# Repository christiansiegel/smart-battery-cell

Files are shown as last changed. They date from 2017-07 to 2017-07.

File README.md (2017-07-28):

# Arduino-based Smart Battery Cell Research Platform

Accessible smart battery cell research platform based on the Arduino environment. Smart battery cells are a recent research direction in the scope of Battery Management Systems (BMS) for large lithium-ion battery packs, where each battery cell is equipped with an individual Cell Management Unit (CMU). The wireless System on Chip (SOC) solution ESP8266 forms the core of the research platform. It is deployed on an off-the-shelf development board and extended with a custom shield. A single-board computer provides the wireless network for the smart battery cells and acts as gateway to a web service for interaction purposes. As a proof-of-concept, a web client is created that communicates with the battery pack via the MQTT protocol.

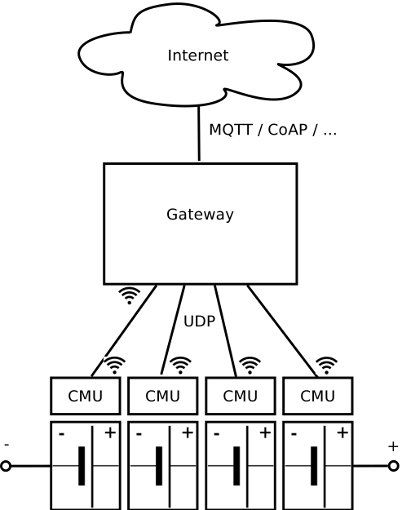
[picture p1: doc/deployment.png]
Deployment Diagram


## Repository Structure

### cloud
Cloud server running MQTT broker and Webserver. See [setup guide](cloud/README.md) for more details.

### cmu
Cell Management Unit Arduino sketch.

### doc
Documentation comprising a [PDF paper](doc/paper.pdf) and a more detailed [PDF report](doc/report.pdf).

### gateway
Gateway Java code. Also contains a [setup guide](gateway/README.md) for a Raspberry Pi 3.

### schematic
Schematic design files (CadSoft EAGLE) of the smart battery cell.

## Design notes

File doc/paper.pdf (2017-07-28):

# Arduino-based Smart Battery Cell Research Platform

Christian Siegel, Aarhus University

(Engineering Research and Development Project)

Abstract—This paper introduces an accessible smart battery cell research platform based on the Arduino environment. Smart battery cells are a recent research direction in the scope of Battery Management Systems (BMS) for large lithium-ion battery packs, where each battery cell is equipped with an individual Cell Management Unit (CMU). The wireless System on Chip (SOC) solution ESP8266 forms the core of the research platform. It is deployed on an off-the-shelf development board and extended with a custom shield. A single-board computer provides the wireless network for the smart battery cells and acts as gateway to a web service for interaction purposes. As a proof-of-concept, a web client is created that communicates with the battery pack via the MQTT protocol.

I. INTRODUCTION
L
ITHIUM Ion (Li-Ion) batteries are utilized in most emerging electrically powered technologies such as electric vehicles, power tools or stationary energy storages. Large battery packs are made of battery cells connected in series and parallel to achieve a desired voltage and capacity. Due to their chemical properties, Li-Ion cells must be operated in strictly specified voltage, current, and temperature ranges to avoid critical damages to the battery cells. State-of-theart battery packs use a central Battery Management Systems (BMS) to monitor cell parameters and control the charge and discharge of cells in a battery pack. Since these BMS are tied to a specific battery pack architecture they need to be customly developed. A recent proposal is to move the battery pack management from a centralized BMS towards individual Cell Management Units (CMU) at the cell level [1]. This leads to more flexibility in composing the battery pack architecture and reduces development time. Furthermore, the reduced battery pack complexity simplifies efficient charge transfer between individual cells, compared to traditional passive balancing, in order to equalize the State of Charge (SoC) of all battery cells. Contributions of this paper. Recent research on smart battery cells was conducted on pricey custom development platforms incorporating powerful microcontrollers and realtime operating systems. Contribution of this paper is to introduce a more accessible smart battery cell research platform based on the Arduino platform, using mainly off-the-shelf hardware components. In section II, related work and its proposed solutions are investigated. Section III discusses and describes the used hardware and modifications made. The software is depicted in section IV. Finally, a conclusion is drawn in section V.

II. RELATED WORK
Previous research was conducted on rather powerful and pricey hardware like a STM32F407 Cortex-M4 microcon-

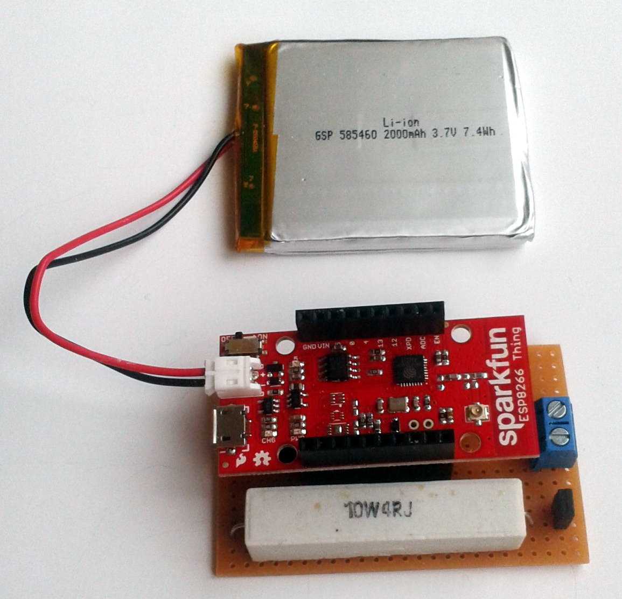
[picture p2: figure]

Fig. 1. Smart battery cell comprised of an ESP8266 development board, an extension shield, and a battery cell.

troller board [1][2]. The microcontroller was connected to the battery cell through a custom designed sensor and control board, which could be interfaced using a Serial Periphal Interface (SPI) bus. The invidual smart cells communicated via a Controller Area Network (CAN) bus connected to the microcontroller boards [1].
Especially communication poses a significant challenge, since wired busses like CAN, Ethernet, Inter-Integrated Circuit (I²C), or Universal Asynchronous Receiver/Transmitter (UART) require a common ground potential. If the smart cells are connected in series, there is no common ground and the bus has to be galvanically separated using e.g. optocouplers.
[3] and [4] propose and demonstrate the use of contactless communication via capacitive coupling for distributed monitoring and controlling of battery cells. This technology can also be applied for communication between smart battery cells. Main disadvantage of this approach is the need for additional communication hardware which is not available off-the-shelf.
[5] proposes wireless communication for monitoring lead acid vehicle batteries. The emerging trend of an Internet of Things (IoT) leads to a range of hardware manufacturers offering low-cost wireless System on Chip (SOC) solutions. A full TCP/IP stack provides a well known, and convenient to use protocol suite for distributed systems.

III. HARDWARE

This section discusses the hardware choices made in order to realise the Arduino-based smart battery cell research platform, which is shown in Fig. 1.

TABLE I
COMPARISON OF WIRELESS SOC MCU PROPERTIES [6][7]
ESP8266 | CC3200
Core | Tensilica L106 | ARM Cortex-M4
Clock | 80 – 160 MHz | 80 MHz
RAM | ∼50 kB usable in station mode | ≤256 kB
Flash | external | external
I/Os | 16 | 27
ADC | 1x 10-bit | 4x 12-bit
2C I | 1 | 1
SPI | 1 | 1
UART | 1 | 2

TABLE II
COMPARISON OF WIRELESS SOC POWER CONSUMPTIONS [6][7]
ESP8266 | CC3200
Tx | ∼145 mA | ∼215 mA
Rx | 56 mA | 59 mA
Modem idle/sleep | 15 mA | 15.3 mA
Deep-Sleep | 10 µA | 4 µA
A. Development Board

To prevent the need for a pricey, customly designed circuit board, the research platform should be based on an offthe-shelf Microcontroller Unit (MCU) development board. In order to further reduce the need of additional hardware, this development board should also comprise a communication interface. As already mentioned in section II, there are wireless SOCs available that meet these requirements, like the Espressif Systems ESP8266¹ or the Texas Instruments CC3200²
. The
MCU properties of the named SOCs are outlined in Table
I. Both MCUs have a 32-bit core. While the CC3200’s core can be clocked at maximum 80 MHz, the ESP8266’s core clock can be increased up to 160 MHz. With around 50 kB of usable RAM in station mode, the ESP8266 has significantly less RAM than the CC3200, which provides 256 kB. Both the ESP8266 and the CC3200 don’t come with internal flash storage. The CC3200 has almost twice the amount of general purpose I/Os than the ESP8266, and four ADCs instead of one. The CC3200’s ADCs also have a higher resolution of 12 bits, compared to the 10-bit ADC of the ESP8266.
Since the CMU is powered by a battery cell, its power consumption is an important figure to maximize the smart battery cell’s capacity. Table II shows the power consumption of both wireless SOCs. The ESP8266 typically draws less current while sending than the CC3200, with ∼145 mA and ∼215 mA respectively. However, the transmission current heavily depends on the WLAN protocol and the transmission power, which can be configured. The receiving current difference is mimimal, with typically 56 mA for the ESP8266 and 59 mA for the CC3200. When the wireless module in sleeping mode, both wireless SOCs also draw almost the same current, with 15 mA and 15.3 mA respectively. In the deepest sleeping mode both devices use ≤10 µA.
Although the ESP8266 is inferior to the CC3200 regarding hardware features, it is chosen as the core of the research

1https://espressif.com/en/products/hardware/esp8266ex/overview2http://www.ti.com/product/CC3200

platform. This is due to a significant lower price while still meeting the requirements for the platform. The SOC is deployed on the SparkFun ESP8266 Thing³ development board. It comprises an ESP8266, flash storage, an antenna, an onboard Li-Po charging circuit, and a JST socket to connect a battery cell. Hence, only the passive cell balancing, and the voltage measurement circuits need to be added externally.

B. Battery
A prismatic, 2000 mAh Li-Po battery with a JST connector is used. It can be directly plugged into the development board. Its capacity is similar to industrial 18650 cylindrical cells, which typically provide around 2500 mAh. This enables it to power the CMU for several hours without recharging. Furthermore, the battery has a built-in protection circuit to prevent damage to the cell if used improperly.
C. Extension Shield
The remaining additional hardware components are combined to an extension shield for the development board.
The SparkFun ESP8266 Thing board doesn’t provide a breakout pin for VBAT . However, there is a not connected (NC) pin in the FTDI pin header (FTDI_BASICPTH) [8]. A jumper wire from the JST battery connector (JP2) to the FTDI pin header maps VBAT to the NC breakout pin.
The voltage of the Li-Po battery cannot directly be measured with the ESP8266’s ADC. To map the maximum voltage of the battery (4.305 V) to the maximum ADC voltage (1 V) a voltage divider, consinsting of a 22 kΩ and a 100 kΩ resistor, is used. This results in a resolution of 5.42 mV. To prevent the discharge of the battery through the resistors while the ESP8226 is switched of, the voltage divider is not wired to ground but to GPIO4. This pin can be configured to output low (ground) while powered on. If the ESP8266 is powered off, GPIO4 has a high impedance and the cell is not discharged. If cells are connected in series, the charging or discharging must be stopped when any of the cells reaches its upper or lower voltage range limits. This requires the cells to be balanced externally. An easy to implement balancing method is passive balancing. It uses switchable resistors to bypass cells which already reached their maximum voltage during charging [9]. Passive balancing is realized using a 4 Ω, 10W power resistor and a FQP30N06L n-channel MOSFET. The MOSFET gate is conncted to GPIO5 which also controls a LED on the development board [8]. Thus, the state of the passive balancing can easily be observed. A pull-down resistor ensures VGS < VGS,of f while the ESP8266 is switched off.
D. Gateway
The ESP8266 can use an existing wireless network (station mode) or provide a network itself (access point mode). The latter allows to operate the smart battery cells in a mesh network. Among other things, this requires routing strategies between the single nodes, which adds complexity to the

3https://www.sparkfun.com/products/13231

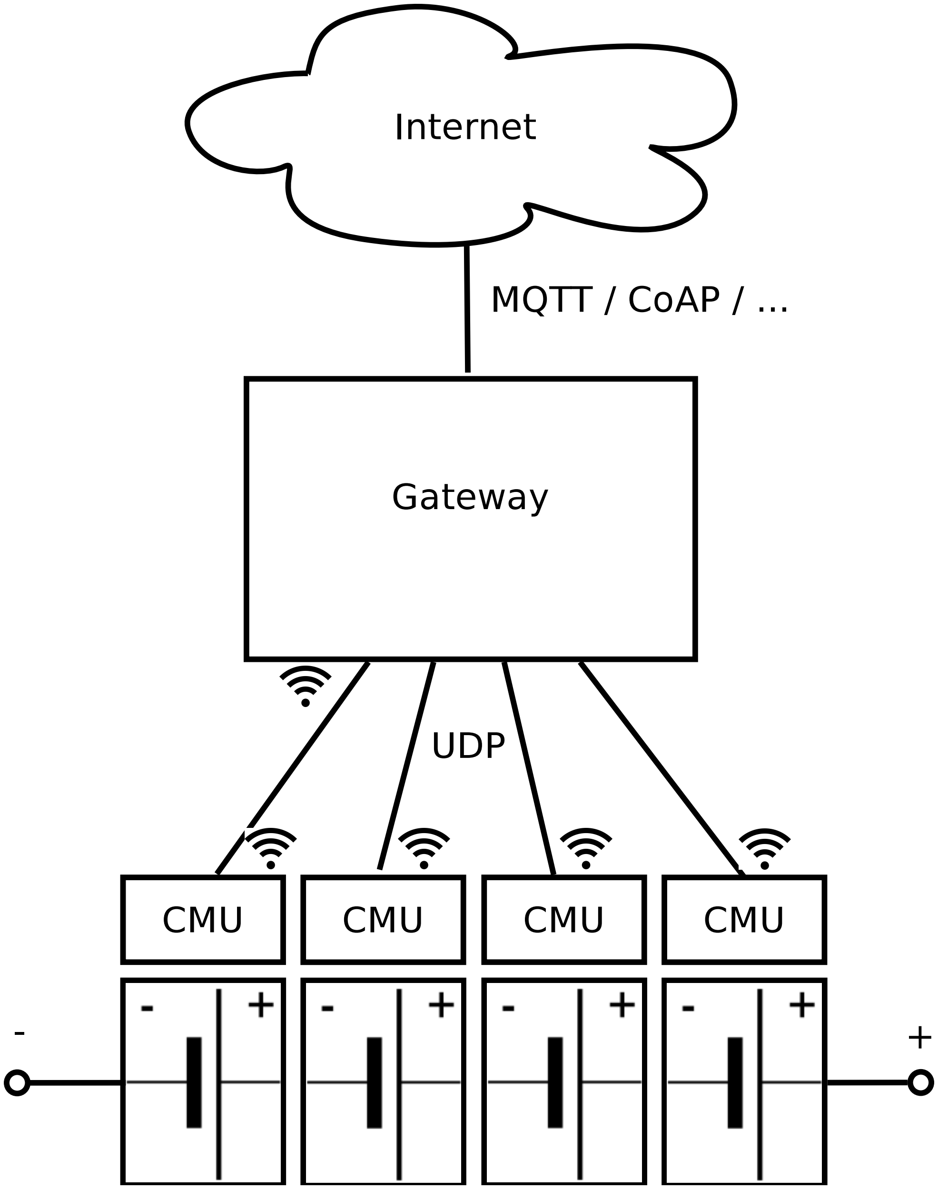
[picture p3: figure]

Fig. 2. Deployment diagram of a battery pack comprising four smart battery cells connected in series, and a common gateway.

distributed communication of the battery pack. For this reason, a single wireless access point is used for all cells. This access point also acts as gateway between the battery pack and its environment. Figure 2 schematically depicts a battery pack consisting of four smart battery cells connected in series. The common gateway provides the WiFi network for the CMU communication and relays communication to some sort of web service.
A Raspberry Pi 3 Model B⁴
single-board computer is used as the gateway. Using the Raspbian GNU/Linux operating system it can be configured to act as wireless router with Dynamic Host Configuration Protocol (DHCP), and run the gateway software.

IV. SOFTWARE

A. Cell Management Unit (CMU)

The CMU software uses the Arduino application programming interface (API). The ESP8266 Arduino core can be added to a standard Arduino installation as a third-party platform package.⁵
The CMU connects to the gateway network with preconfigured Service Set Identifier (SSID) and passphrase. After establishing a connection to the network, the state of the smart battery cell is periodically broadcasted via UDP messages. The state comprises the current cell voltage in mV, the balancing state (on = 1 / off = 0), and the balancing mode (manual = 0 / automatic = 1). The state message has a size of five bytes. Table III illustrates the message structure.

TABLE III
CELL STATE MESSAGE STRUCTURE
Byte | 1 | 2 | 3 | 4 | 5
| Message ID = 0 | Voltage [mV] | | Balancing state | Balancing mode

4https://www.raspberrypi.org/products/raspberry-pi-3-model-b/5https://github.com/esp8266/Arduino

All CMUs continously check for incoming messages and handle them. If the state message of another CMU is received, this smart battery cell’s state is cached in order to calculate the battery pack’s average cell voltage. Since no topology information is available, the single identifier of a CMU is its IP address, which is assigned by the gateway. In a class C network, only the last octet of the address varies. Hence, this octet can be used as unique ID, as shown in the following example.

192 . 168 . 0 . 42
|{z}
CMU
ID
By saving the state of each smart battery cell in the network, the number of cells in a network is bounded by the CMU memory. Furthermore, in a class C network the number of assignable addresses is limited to 254, which should be sufficient in this research context. To overcome memory limits in large battery packs, CMUs could be clustered in multicast groups. These groupy can then just share aggregated information.
Every CMU’s state is marked with the millisecond timestamp of the last received update. If an entry is older then two seconds, this entry is ignored when calculating aggregated values. This allows to dynamically reconfigure the battery pack by adding or removing smart battery cells from the network. To control the passive balancing of the smart battery cells, another message type is defined. The balancing control message has a size of three bytes. The structure of the message is shown in Table IV.

TABLE IV
BALANCING CONTROL MESSAGE STRUCTURE
Byte | 1 | 2 | 3
| Message ID = 1 | Balancing state | Balancing mode

If the balancing mode is set to manual, the balancing circuit can be turned on and off by setting the balancing state. On the other hand, if the balancing mode is set to automatic, the cell continously compares its cell voltage to the aggregated battery pack average voltage. If the own voltage is higher than the average, the passive balancing is automatically activated.

B. Gateway
The gateway software, written in Java, is structured in four main parts consisting of configuration, cell communication, web communication, and the battery pack domain model (see Fig. 4).
The cells client listens for broadcasted CMU state messages on the network and updates the model of the battery pack accordingly. It also forwards change requests of the balancing state and mode to the individual CMUs.
The web client gets the state of the battery pack and its single cells from the model. This information can then made accessible via an arbitrary protocol. As a proof of concept, a MQTT client is implemented. It periodically publishes every single cell state, as well as the minimum, maxmimum, and

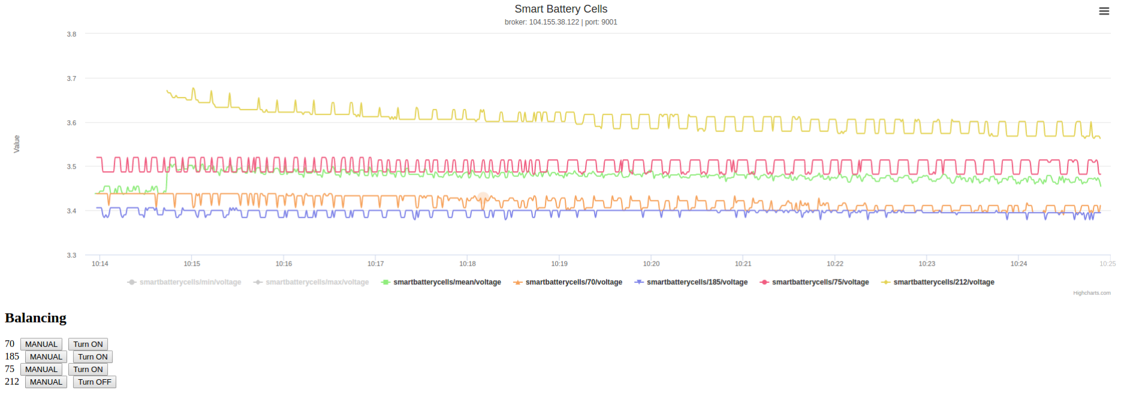
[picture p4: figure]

Fig. 3. Screenshot of the web based user interface. The cell with ID 212 (yellow) was added to the battery pack during runtime. This caused the average battery pack voltage (green) to raise. The passive balancing of the newly added smart battery cell was manually activated, what caused a faster voltage drop over time.

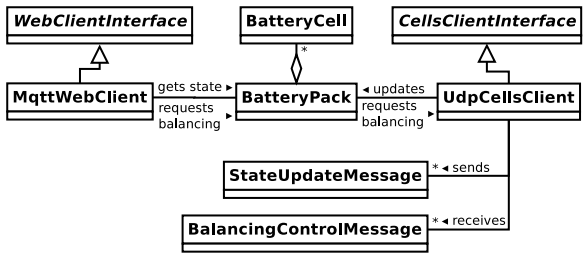
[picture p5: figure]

Fig. 4. Gateway classes for web and cells communication and battery pack domain model.

average battery pack voltages. It also subscribes to a balancing topic for every smart battery cell and forwards these requests to the model.
In order to enable convenient changes to configuration parameters, a YAML file is used. It is loaded at startup to create a configuration object, which subsequently is used by the rest of the software.
C. User Interface
The most basic user interface can be a class that implements the WebClientInterface and periodically outputs the battery pack state to the Java console.
As mentioned in section IV-B, a MQTT client is implemented to publish the cell state to a MQTT broker. A simple web based user interface is used to display this information. The balancing mode can be controlled via buttons that trigger the publishing of a control message to the MQTT broker. Fig. 3 shows a screenshot of the user interface with four battery cells.
V. CONCLUSION
This paper introduced an Arduino-based smart battery cell research platform. The platform comprises an ESP8266 WiFi SOC on the inexpensive Sparkfun ESP8266 Thing development board. Additional hardware for cell voltage measurement and passive balancing is combined on a simple extension shield. The CMUs communicate via UDP/IP on a WiFi network created by a Raspberry Pi 3 Model B, which also acts as a gateway. The gateway runs a software to relay cell state information and balancing control messages between the cell network and a web service. As a proof-of-concept the communication between the battery pack and a graphical web interface was implemented via the MQTT protocol.
The smart battery cell research platform software currently only supports basic features which are to be researched and extended using this platform in the future. Furthermore, the ADC showed jitter which has to be reduced by additional hardware and/or software filtering.

REFERENCES

[1] S. Steinhorst, M. Lukasiewycz, S. Narayanaswamy, M. Kauer, and
S. Chakraborty, “Smart cells for embedded battery management,” in Proceedings of the 2nd International Conference on Cyber-Physical Systems, Networks, and Applications (CPSNA 2014), pp. 59–64, 9 2014.
[2] S. Steinhorst and M. Lukasiewycz, “Topology identification for smart cells in modular batteries,” in Proceedings of the Conference on Design, Automation and Test in Europe (DATE 2015), pp. 1–4, 3 2015.
[3] N. Martiny, T. Mhlbauer, S. Steinhorst, M. Lukasiewycz, and A. Jossen, “Digital data transmission system with capacitive coupling for in-situ temperature sensing in lithium ion cells,” Journal of Energy Storage, vol. 4, pp. 128–134, 2015.
[4] V. Lorentz, “Electrical energy storage: Distributed battery monitoring.” EES 2012 Electrical Energy Storage Exhibition Munich, Nov. 2012. http://media.nmm.de/91/lorentz fraunhofer-iisb 14.11.2012 10. 30 26767091.pdf.
[5] M. Schneider, S. Ilgin, N. Jegenhorst, R. Kube, S. Pttjer, K. R. Riemschneider, and J. Vollmer, “Automotive battery monitoring by wireless cell sensors,” in Instrumentation and Measurement Technology Conference (I2MTC), 2012 IEEE International, pp. 816–820, May 2012.
[6] Espressif, “ESP8266EX Datasheet 2016 v4.9.” https://espressif.com/sites/default/files/documentation/0a-esp8266ex datasheet en.pdf, 2016. Accessed: 2016-08-30.
[7] Texas Instruments, “CC3200 SimpleLinkTM Wi-Fi
R and Internet-of-Things Solution, a Single-Chip Wireless MCU.” http://www.ti.com/lit/gpn/cc3200, Feb. 2015. Accessed: 2016-08-30.
[8] Jim Lindblom, “SparkFun ESP8266 Thing.” Schematic, https://cdn.sparkfun.com/datasheets/Wireless/WiFi/SparkFun ESP8266 Thing.pdf, May 2015. Accessed: 2016-10-16.
[9] M. Isaacson, R. Hollandsworth, P. Giampaoli, F. Linkowsky, A. Salim, and V. Teofilo, “Advanced lithium ion battery charger,” in Battery Conference on Applications and Advances, 2000. The Fifteenth Annual, pp. 193–198, IEEE, 2000.

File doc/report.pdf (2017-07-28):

# Arduino-based Smart Battery Cell Research Platform

### Engineering Research and Development Project

Christian Siegel 201503241

# Contents

1 Introduction | 1
2 Platform Selection | 2
3 Additional Hardware | 6
4 Software | 12
5 Conclusion | 16
Bibliography | 17
A Zip Archive | 18
B Setup Gateway | 19
C Setup Cloud Server | 22

i

# Chapter 1

# Introduction

Lithium Ion (Li-Ion) batteries are utilized in most emerging electrically powered technologies such as electric vehicles, power tools or stationary energy storages. Large battery packs are made of battery cells connected in series and parallel to achieve a desired voltage and capacity. Due to their chemical properties, Li-Ion cells must be operated in strictly specified voltage, current and temperature ranges to avoid critical damages to the battery cells. State-of-the-art battery packs use a central Battery Management Systems (BMS) to monitor cell parameters and control the charge and discharge of cells in a battery pack. Since these BMS are tied to a specific battery pack architecture they need to be customly developed. A recent proposal is to move the battery pack management from a centralized BMS towards individual Cell Management Units (CMU) at the cell level [1]. This leads to more flexibility in composing the battery pack architecture and reduces development time. Furthermore, the reduced battery pack complexity simplifies efficient charge transfer between individual cells instead of traditional passive balancing to equalize the State of Charge (SoC) of all battery cells.
Recent research on smart battery cells was conducted on pricey custom development platforms incorporating powerful microcontrollers and real-time operating systems. Contribution of this project is to introduce a more accessible smart battery cell research platform based on the Arduino¹ platform using mostly publicly available hardware. Moreover, an analysis of the benefits and limits of the proposed prototype is conducted.

1
https://www.arduino.cc/

1

# Chapter 2

# Platform Selection

The core of the smart battery cell research platform shall be some sort of microcontroller platform that needs to be selected. The final research platform shall be able to measure the cell voltage as well as perform passive cell balancing. At the same time the overall cost and external hardware requirements shall be kept low.
This chapter compares different communication technologies and microcontroller platforms to finally select an off-the-shelf development board as basis for the smart battery cell research platform.

### Previous Work

Previous research was conducted on rather powerful and pricey hardware like a STM32F407 Cortex-M4 microcontroller board [1][2]. The microcontroller is connected to the battery cell through a custom designed sensor and control board, which can be interfaced using Serial Periphal Interface (SPI). The invidual smart cells communicate via a Controller Area Network (CAN) bus connected to the microcontroller boards [1].

### Communication

Especially communication poses a significant challenge, since wired busses like CAN, Ethernet, Inter-Integrated Circuit (I²C) or Universal Asynchronous Receiver/Transmitter (UART) require a common ground potential. If the smart cells are connected in series there is no common ground and the bus has to be decoupled using e.g. optocouplers.
While I²C and UART interfaces are usually integrated in state-of-the-art microcontrollers, CAN and Ethernet require additional hardware controllers. These controllers increase complexity, price and power consumption of the research platform. Moreover, UART is designed for 1:1 connections and would restrict the network topology.
[3] and [4] propose and demonstrate the use of contactless communication via capacitive coupling for distributed monitoring and controlling of battery cells. This could also be used for communication between smart battery cells. Main disadvantage of this approach is the need for additional communication hardware which is not available off-the-shelf.
[5] proposes wireless communication for monitoring lead acid vehicle batteries. The emerging trend of an Internet of Things (IoT) leads to a range of hardware manufacturers offering lowcost wireless system on chip (SOC) solutions. Devices like the Espressif Systems ESP8266 ¹

1
https://espressif.com/en/products/hardware/esp8266ex/overview

2

and the Texas Instruments CC3200 ²
comprise a regular microcontroller combined with a WiFi module. A full TCP/IP stack provides a well known and convenient to use protocol suite for distributed systems.

### Microcontroller

With a focus on wireless solutions the selection of microcontroller units (MCU) can be narrowed down to the ones contained in the ESP8266 and the CC3200. The previously used STM32F407 microcontroller is also added to table 2.1 for comparison.

Table 2.1: Comparison of MCU properties [6][7][8]

ESP8266 | CC3200 | STM32F407
Core | Tensilica L106 | ARM Cortex-M4 | ARM Cortex-M4
Clock | 80 – 160 MHz | 80 MHz | 168 MHz
RAM | ∼50 kB usable in station mode | ≤256 kB | 192 kB
Flash | external | external | 512 kB – 1024 kB
I/Os | 16 | 27 | 82 – 140
ADC | 1x 10-bit | 4x 12-bit | 16 – 24x 12-bit
I 2C | 1 | 1 | 3
SPI | 1 | 1 | 3
UART | 1 | 2 | 2

All MCUs have a 32-bit core. While the CC3200’s core can be clocked at maximum 80 MHz, the ESP8266’s core clock can be increased up to 160 MHz reaching the clock speed of the STM32F407. With around 50 kB of usable RAM in station mode the ESP8266 has significantly less RAM than the STM32F407 or the CC3200 which provide 192 kB and 256 kB respectively. Both the ESP8266 and the CC3200 don’t come with internal Flash. The STM32F407 cleary surpasses both wireless SOCs in regard to peripheral interfaces. The CC3200 still has almost twice the amount of general purpose I/Os than the ESP8266 and four ADCs instead of one. The CC3200’s ADCs also come with higher 12-bit precision instead of 10-bit.

### Power Consumption

Since the CMU is powered by a battery cell, its power consumption is an important figure to maximize the smart battery cell’s capacity. Table 2.2 shows the power consumption of both wireless SOCs and the STM32F407 for comparison.

Table 2.2: Comparison of power consumptions [6][7][8]

ESP8266 | CC3200 | STM32F407
Tx | ∼145 mA | ∼215 mA | -
Rx | 56 mA | 59 mA | -
Modem idle/sleep | 15 mA | 15.3 mA | 36 mA
Deep-Sleep | 10 µA | 4 µA | 1.7 µA

The ESP8266 typically draws less current while sending than the CC3200 with ∼145 mA and ∼215 mA respectively. However, the transmission current heavily depends on the WLAN

2
http://www.ti.com/product/CC3200

3

protocol and the transmission power, which can be configured. The receiving current difference is mimimal with typically 56 mA for the ESP8266 and 59 mA for the CC3200. When the wireless module is put to sleep both wireless SOCs also draw almost the same current with 15 mA and 15.3 mA respectively. This is only half the power consumed by the STM32F407. In the deepest sleep mode all devices use ≤10 µA.

### Development Board

To avoid the need of pricey custom printed circuid boards for the smart battery cell research platform, a range of publicly available development boards for the ESP8266 and the CC3200 platform are investigated.
Since the ESP8266 is more common on the privat market there are great amounts of different development boards available. Basic ESP8266 modules comprised of the ESP8266 chip, external flash and an antenna are available for less than $5.³ However, these simple modules usually can’t be used with breadboards and don’t contain convenient pin-headers for flashing or a reset button. The named features are added by breakout boards like the Adafruit HUZZAH ESP8266 Breakout, which extends the basic ESP8266 ESP-12 module with buttons, LEDs, 5 V compatible UART interface, 3.3 V voltage regulator and breadboard compatible pin breakouts for less than $10.⁴ The SparkFun ESP8266 Thing additionally comes with an on-board Li-Po charging circuit and a socket for SparkFun’s prismatic Li-Po batteries for $15.95.⁵ When using the SparkFun ESP8266 Thing only the passive cell balancing circuit and a voltage divider for cell voltage measurement with the on-board ADC need to be added externally.
The development boards offered for the CC3200 platform are more focused on industrial evaluation and development. The SimpleLink Wi-Fi CC3200 LaunchPad available for $29.99 comprises various additional hardware.⁶ This, for example, includes a FTDI USB driver for programming and debugging. Other boards like the RedBearLab WiFi Micro CC3200 Development Board are targeted to private users. It has an Arduino form factor. However, this board also costs around twice as much as the most expensive ESP8266 board listed previously.⁷

### Development Environment

Both ESP8266 and CC3200 can be programmed using the Arduino environment. This enables a flat learning curve and knowledge transfer from previous Arduino experience.
The ESP8266 Arduino core can be added to a standard Arduino installation as a thirdparty platform package.⁸ For the CC3200 a whole fork of Arduino, named Energia, has to be installed.⁹
By using the common Arduino API the written software is independent from the hardware platform. This increases the portability of the software. In case of future hardware requirements changes this allows to easily switch to another platform.

3
https://www.amazon.com/, effective 2016-10-15.
4
https://www.adafruit.com/products/2471, effective 2016-10-15.
5
https://www.sparkfun.com/products/13231, effective 2016-10-15.
6
http://www.ti.com/tool/cc3200-launchxl, effective 2016-10-15.
7
http://www.makershed.com/products/wifi-cc3200-board, effective 2016-10-15.
8
https://github.com/esp8266/Arduino
9
https://github.com/energia/Energia

4

### Platform Choice

The CC3200 surpasses the ESP8266 in regards of available RAM and hardware peripherals. The ESP8266 scores with a lower transmission current, better suited development boards and a significantly lower price tag. The inferior hardware peripherals of the ESP8266 still meet the requirements of the smart battery cell research platform. This is why the ESP8266 in combination with SparkFun ESP8266 Thing board are chosen as basis for the smart battery cell research platform. Figure 2.1 shows the SparkFun ESP8266 Thing.

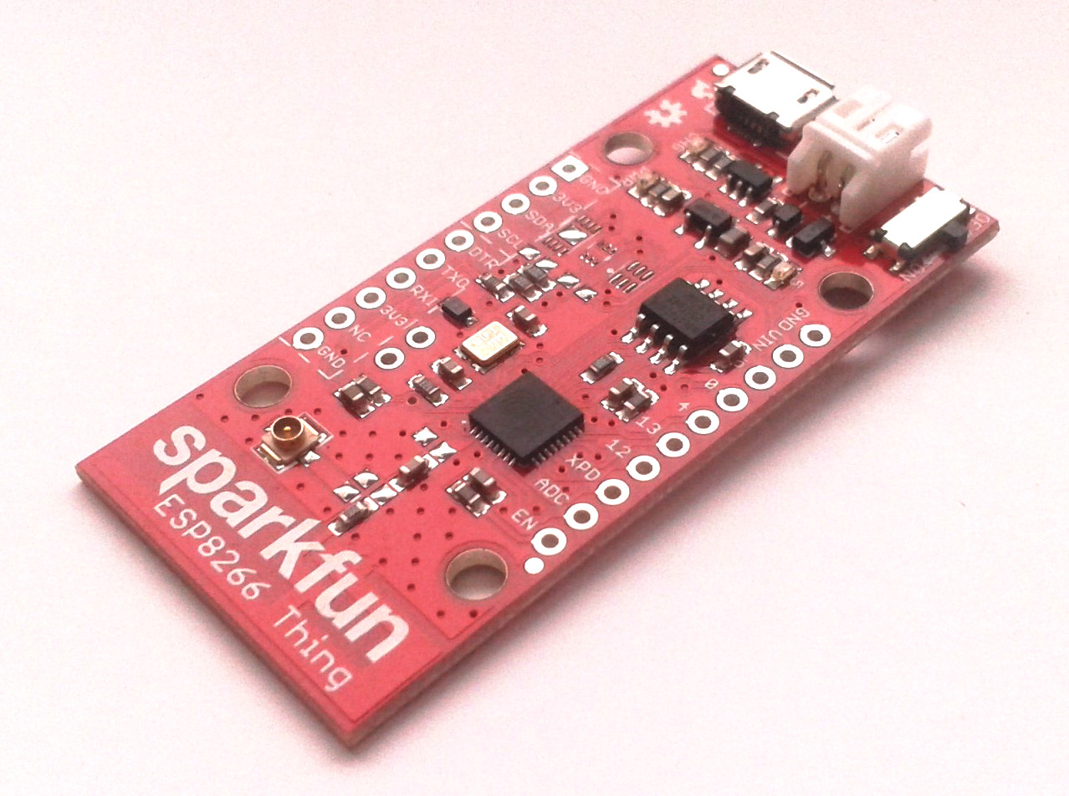
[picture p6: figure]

Figure 2.1: SparkFun ESP8266 Thing

5

# Chapter 3

# Additional Hardware

The ESP8266 development board needs to be extended with additional hardware to form a smart battery cell. The needed components are outlined in the following sections.

### Smart Battery Cell

Li-Po Cell

The SparkFun ESP8266 Thing has a JST connector for Li-Po batteries. Prismatic Li-Po cells with a JST connector can also be sourced from SparkFun. The capacities of the offered battery cells range from 40 to 6000 mAh. A Li-Po battery with a capacity of 2000 mAh is chosen to be able to power the CMU several hours without recharging. This capacity also comes closest to 18650 cylindrical cells which typically provide around 2500 mAh. Furthermore, the battery has a built-in protection circuit to prevent damage to the cell if used improperly. Figure 3.1 shows the used Li-Po cell.

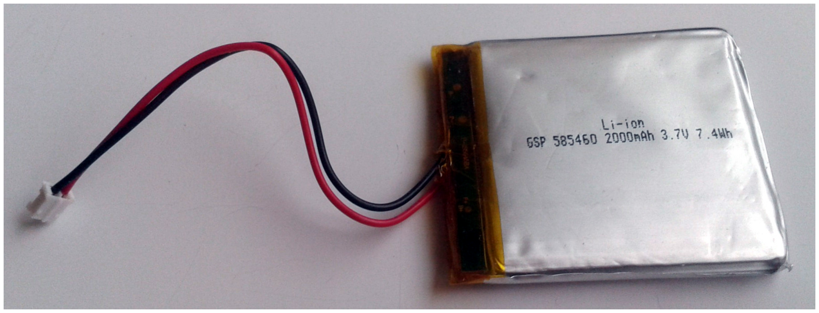
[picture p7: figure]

Figure 3.1: Prismatic 2000 mAh Li-Po cell

Battery Breakout

The SparkFun ESP8266 Thing board doesn’t provide a breakout pin for VBAT . However, there is a not connected (NC) pin in the FTDI pin header (FTDI_BASICPTH) [9]. A jumper wire from the JST battery connector (JP2) to the FTDI pin header maps VBAT to the NC breakout pin. Figures 3.2 and 3.3 show the changed headers schematic and the SparkFun ESP8266 Thing with added jumper wire respectively.

6

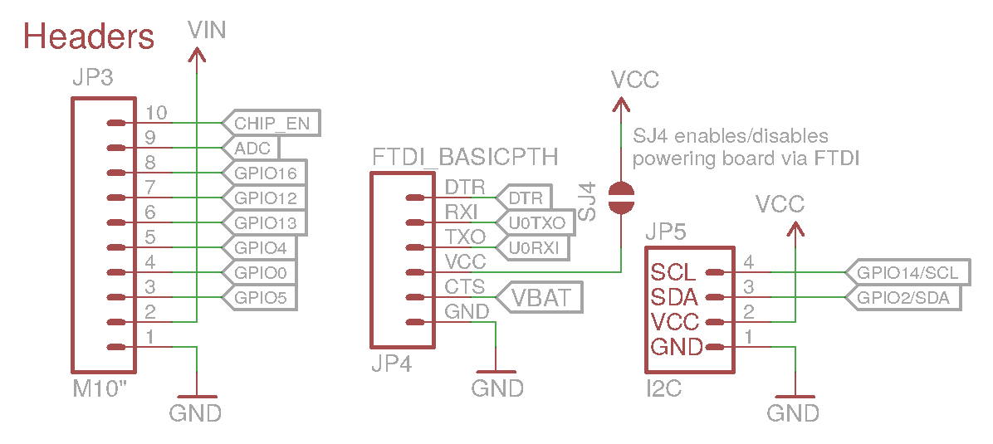
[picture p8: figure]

Figure 3.2: Headers section of the SparkFun ESP8266 Thing schematic with added VBAT breakout.

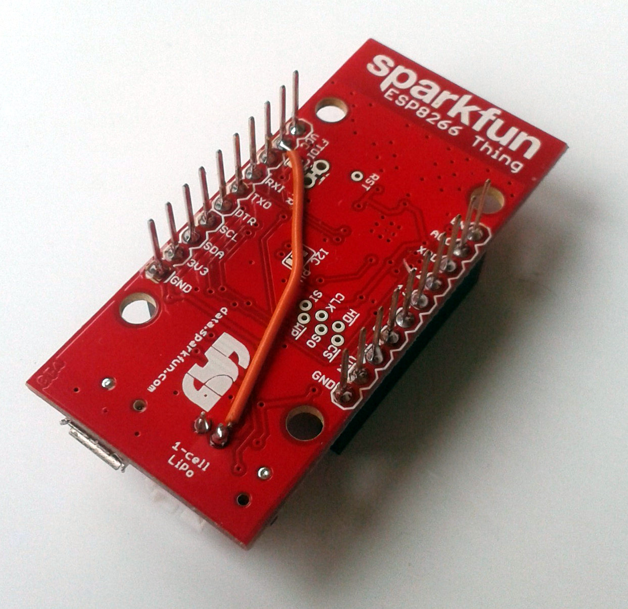
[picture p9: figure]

Figure 3.3: SparkFun ESP8266 Thing with jumper wire to breakout VBAT .

Voltage Measurement

The voltage of the Li-Po battery cannot directly be measured with the ESP8266’s ADC. To map the maximum voltage of the battery (4.305 V) to the maximum ADC voltage (1 V) a voltage divider is used. Figure 3.4 shows the schematic of the voltage divider.
Equation 3.2 shows the voltage ratio with R1 = 100 kΩ and R2 = 22 kΩ.

UBAT =

R1 + R2
R2
- UADC | (3.1)

UADC =

11
61
- UBAT | (3.2)

To prevent the discharge of the battery through the resistors while the ESP8226 is switched of, the voltage divider is not wired to ground but GPIO4. This pin can be configured to output low (ground) while powered on. If the ESP8266 is powered off, GPIO4 has a high impedance and the cell is not discharged.

7

Figure 3.4: Voltage divider schematic.

Passive Balancing

If cells are connected in series the charging or discharging must be stopped when any of the cells reaches its upper or lower voltage range limits. This requires the cells to be balanced externally. An easy to implement balancing method is passive balancing. It uses switchable resistors to bypass cells which already reached their maximum voltage during charging [10].
Passive balancing is realized using a 4 Ω, 10W power resistor and a FQP30N06L n-channel MOSFET. The resistor discharges the cell with 0.925 A at 3.7 V. The MOSFET gate is conncted to GPIO5 which also controls a LED on the development board [9]. Thus, the state of the passive balancing can easily be observed. A pull-down resistor ensures VGS < VGS,of f while the ESP8266 is switched off.
Figure 3.5 shows the schematic of the passive balancing circuit.

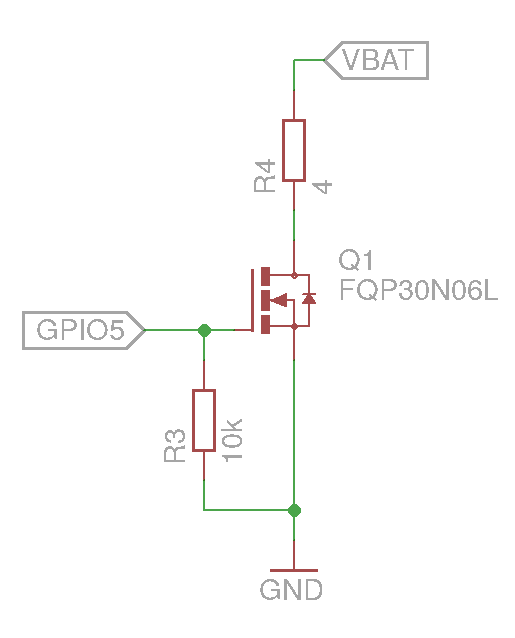
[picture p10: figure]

Figure 3.5: Passive balancing circuit schematic.

Shield

All additional hardware mentioned so far can be connected to the development board using a prototyping breadboard. For increased convenience when working with multiple smart battery cells, the hardware is combined to a smart battery cell extension shield for the SparkFun ESP8266 Thing. For easy creation and modification a perfboard is used.
Besides the voltage divider and passive balancing circuit the shield also comprises a tworowed pin header to plug the development board into as well as a terminal for VBAT and ground. The terminal circuit can be interrupted with a jumper. This can be useful if multiple smart battery cells are connected in series while e.g. connected to the same PC for programming. Without disconnecting the series connection this would cause a hazardous potential difference between the ground potentials connected to the PC.

8

Figures 3.6 and 3.7 show the whole shield schematic and a picture of the assembled shield respectively.

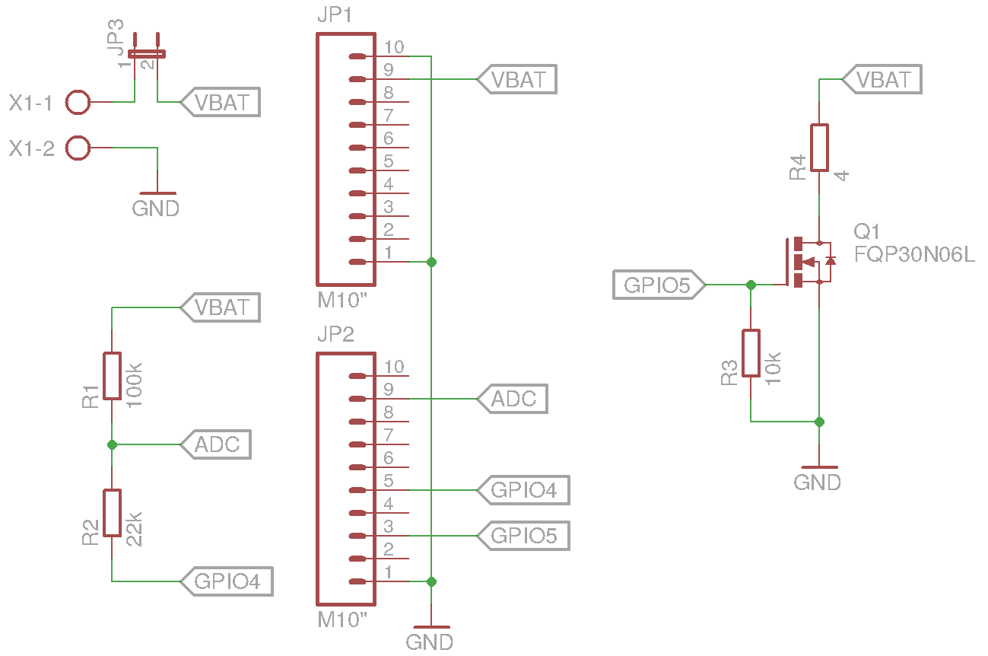
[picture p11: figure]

Figure 3.6: Smart battery cell shield schematic.

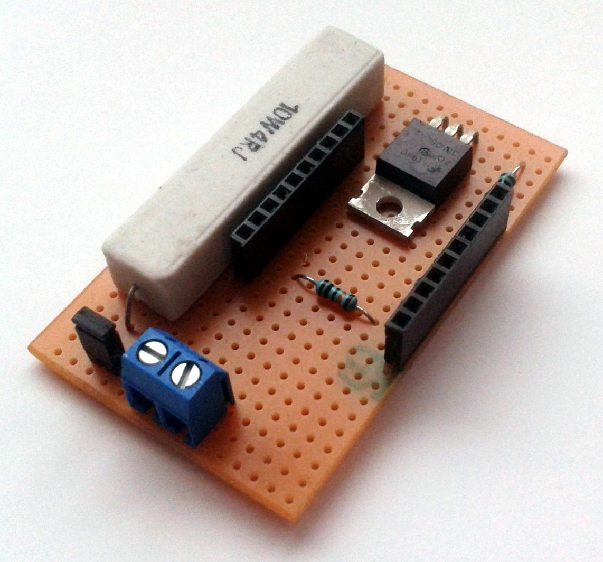
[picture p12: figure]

Figure 3.7: Assembled smart battery cell shield.

### FTDI Adapter

To upgrade the ESP8266’s firmware it has to be downloaded to the flash storage via UART. A convenient way to do this is by using a FTDI USB to serial integrated circuit (IC). This interface can also be used to communicate with the device using a serial terminal.
Since the operating voltage of the ESP8266 is 3.3 V the adapter should operate at the same voltage.
The bootloader for downloading the software is only active for a short time after a reset and then starts the actual firmware. Thus, the device needs to be reset before downloading the

9

firmware. With the FTDI header’s Data Terminal Ready (DTR) pin beeing wired to the reset pin of the ESP8266, the reset can be automated if the adapter provides a DTR line [9]. SparkFun’s SparkFun FTDI Basic Breakout - 3.3V ¹ provides the required properties and is therefore used to upgrade the smart battery cell’s firmware.
As described in 3.1.2, VBAT is mapped to the NC pin of the FTDI pin header. This collides with the Clear To Send (CTS) pin of the FTDI adapter which is not required for this application. To prevent damages to the FTDI IC, this pin must not be connected to the modified pin header. Figure 3.8 shows a picture of the SparkFun FTDI Basic Breakout - 3.3V with omitted CTS and 3V3 power pin.

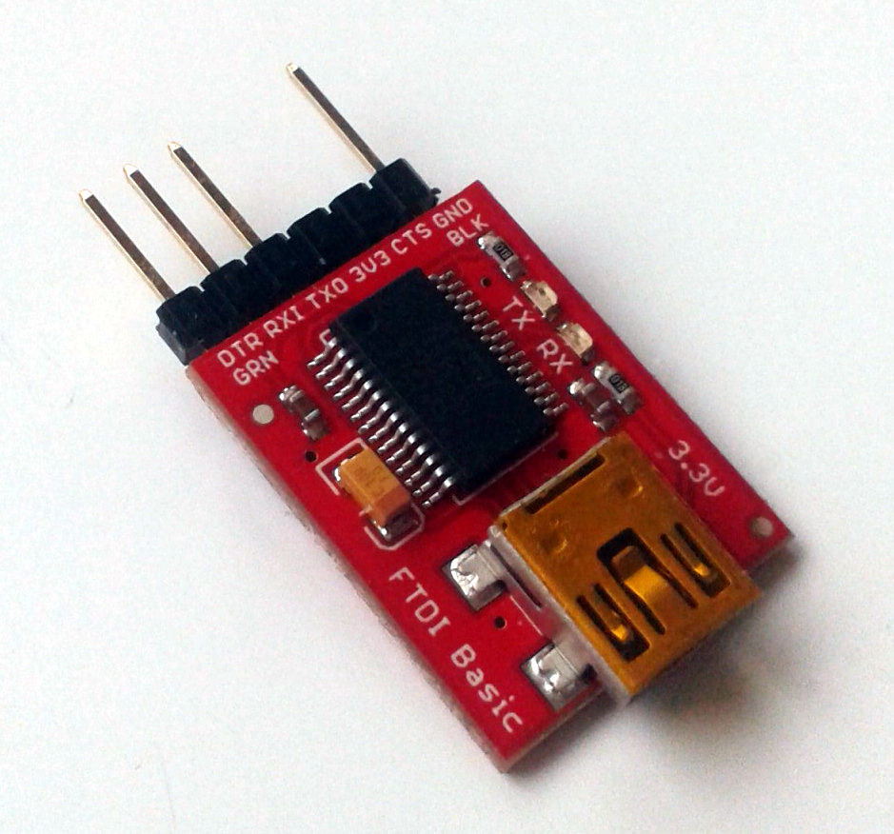
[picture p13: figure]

Figure 3.8: SparkFun FTDI Basic Breakout - 3.3V with omitted CTS and 3V3 power pins.

### Consumer

To have a simple consumer for up to five smart battery cells connected in series a 24 V, 5W light bulb is used. It is mounted on a perfboard together with an on-off switch and a terminal. Figure 3.9 shows the consumer circuit board.

### Gateway

The ESP8266 can use an existing wireless network (station mode) or provide a network itself (access point mode). This allows to operate the smart battery cells in a mesh network. Among other things, this requires routing strategies between the single nodes, which adds complexity to the distributed communication of the battery pack. For this reason, a single wireless access point is used for all cells. This access point also acts as gateway between the smart battery cells and the outside world.
A Raspberry Pi 3 Model B²
single-board computer is used as the gateway. Using the Raspbian GNU/Linux operating system it can be configured to act as wireless router with Dynamic Host Configuration Protocol (DHCP). Furthermore, it can run a gateway software that acts as gateway between the wireless cell network and a network connected via the ethernet interface. Figure 3.10 schematically depicts four smart battery cells connected in series and forming a battery pack. The common gateway provides the WiFi network for the CMU communication and acts as relay between the battery pack and some sort of web service.

1
https://www.sparkfun.com/products/9873
2
https://www.raspberrypi.org/products/raspberry-pi-3-model-b/

10

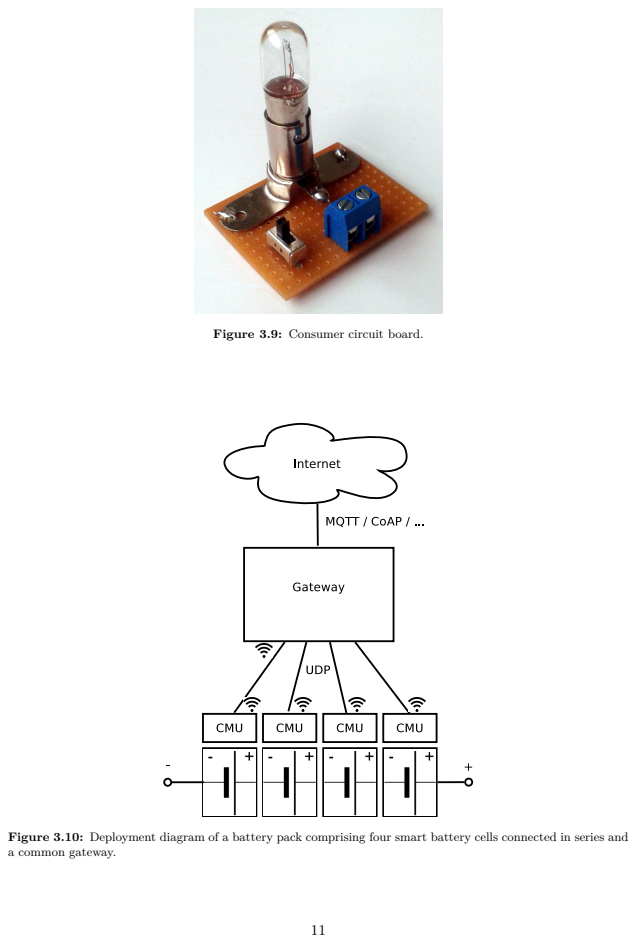
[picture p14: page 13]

Figure 3.9: Consumer circuit board.

Figure 3.10: Deployment diagram of a battery pack comprising four smart battery cells connected in series and
a common gateway.

# Chapter 4

# Software

### Cell Management Unit

The CMU software uses the Arduino application programming interface (API) and is thus roughly structured in the setup() and the loop() part.
During the setup the serial interface and general-purpose inputs/outputs (GPIO) are initialized. Furthermore, the CMU connects to the gateway network with preconfigured service set identifier (SSID) and passphrase. After establishing a connection to the network a WifiUDP socket is initialized and bound to port 4444.
During the loop phase the CMU periodically broadcasts its state to the network. The state comprises the current cell voltage in mV, balancing state (on = 1 / off = 0), and balancing mode (manual = 0 / automatic = 1). The state message has a size of five bytes. Table 4.1 illustrates the message structure.

Table 4.1: Cell state message

Byte | 1 | 2 | 3 | 4 | 5
| Message ID = 0 | Voltage [mV] | | Balancing state | Balancing mode

All CMUs continously check for incoming messages and handle them. If the state message of another CMU is received, this smart battery cell’s state is cached in order to calculate the battery packs average voltage. Since no topology information is available, the single identifier of a CMU is its IP address assigned by the gateway. In a class C network only the last octet of the address varies and can thus be used as unique ID as shown in the following example.

192 . 168 . 0 . 42
|{z}
CMU
ID

This ID can also be used as array index to store the state information of all cells in the network. Every CMU’s state in the array is marked with a millisecond timestamp of the last update. If an entry is older then two seconds, this entry is ignored when calculating aggregated values. This allows to physically reconfigure the battery pack by adding or removing smart battery cells.
The number of cells in a network is bounded by the CMU’s RAM size to hold the state array. Furthermore, in a class C network the number of assignable addresses is limited to 254, which should be sufficient in this research context. To overcome memory limits in large battery packs,

12

CMUs could be clustered in multicast groups and just share aggregated information between these groups.
To control the passive balancing of the smart battery cells another message type is defined. The balancing control message has a size of three bytes. The structure of the message is shown in table 4.2.

Table 4.2: Balancing control message

Byte | 1 | 2 | 3
| Message ID = 1 | Balancing state | Balancing mode

This message is intended to be sent from the gateway to change the smart battery cell’s balancing behaviour. If the balancing mode is set to manual the balancing circuit can be turned on and off by setting the balancing state. On the other hand, if the balancing mode is set to automatic the cell continously compares its cell voltage to the aggregated battery pack voltage. If the own voltage is higher than the average, the passive balancing is automatically activated. Thus, the balancing state parameter has no effect.

### Gateway

The gateway software is written in Java using Apache Ant to automate the build process and Apache Ivy to resolve dependencies. The software is structured in four main parts consisting of configuration, cell communication, web communication and the battery pack domain model. Figure 4.1 shows the main classes for web and cells communication as well as the battery

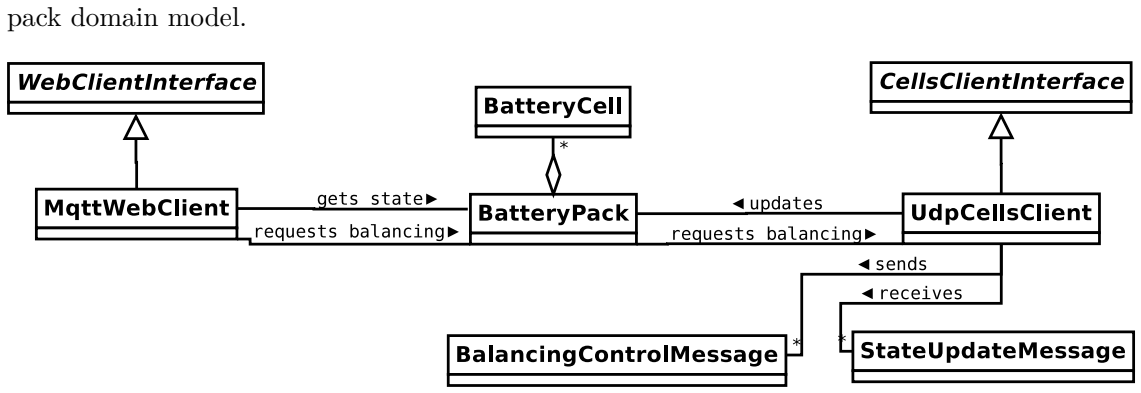
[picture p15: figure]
pack domain model.

Figure 4.1: Gateway classes for web and cells communication and battery pack domain model.

The cells client listens for broadcasted CMU state messages on the network and updates the model of the battery pack accordingly. The cells client also forwards change requests of the balancing state and/or mode to the individual CMUs.
The web client gets the state of the battery pack and its single cells from the model. This information can then made accessible via an arbitrary protocol. As a proof of concept a MQTT client is implemented. It periodically publishes every single cell state as well as the minimum, maxmimum and average battery pack voltages. It also subscribes to a balancing topic for every smart battery cell and forwards these requests to the model.
In order to enable convenient changess of configuration parameters a YAML file is used. It is loaded at startup by the ConfigLoader which subsequently creates the Config object (see figure 4.2).

13

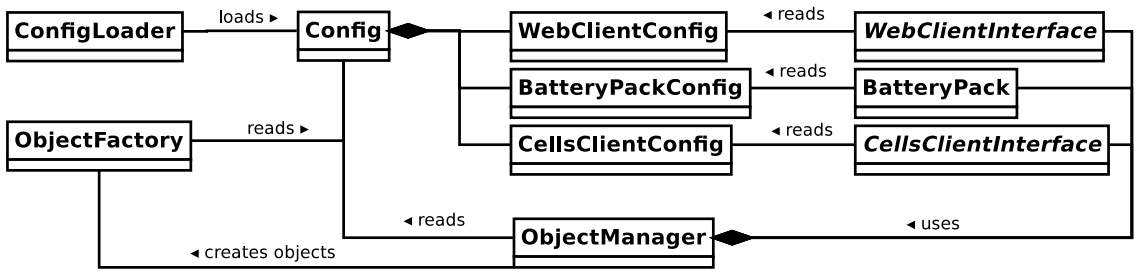
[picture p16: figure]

Figure 4.2: Configuration and object management classes.

The configuration is then read by the ObjectManager which uses the ObjectFactory to instantiate the objects depicted in figure 4.1. Individual configuration parameters like e.g. the cell communication port are accessed by the according objects themselves.
Appendix B describes the single steps to setup the Raspberry Pi 3 to provide the WiFi network and run the gateway software.

### User Interface

The most basic user interface can be a class that implements the WebClientInterface and periodically outputs the battery pack state to the Java console.
As mentioned in section 4.2 a MQTT client was implemented to publish the cell state to a MQTT broker. A simple web based user interface is used to display this information. The Eclipse Paho JavaScript Client¹ MQTT library allows to connect to a MQTT broker via WebSockets. The received cell and aggregated pack voltages are then displayed using the Highcharts²
charting library. The balancing mode can be controlled via buttons that trigger the publishing of a control message to the MQTT broker.
Figure 4.3 shows a screenshot of the user interface showing four battery cells.

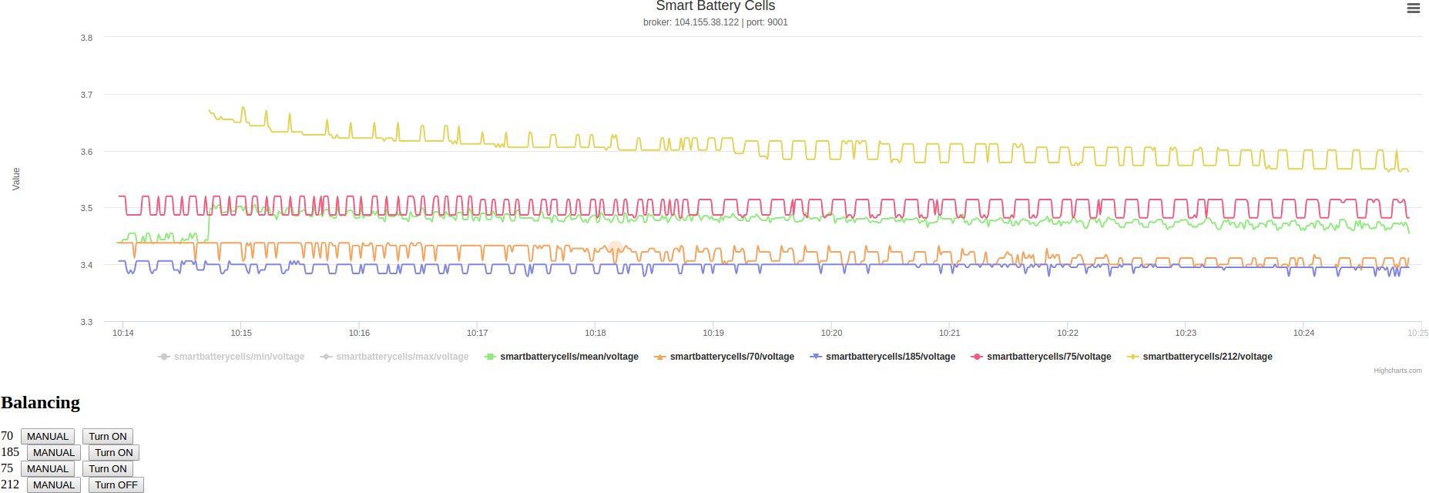
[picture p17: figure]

Figure 4.3: Screenshot of the web based user interface.

The cell with ID 212 (yellow) was added to the battery pack during runtime. This caused the average battery pack voltage (green) to rise. The passive balancing of the newly added smart battery cell was manually activated which causes a faster voltage drop over time.

1
https://eclipse.org/paho/clients/js/
2
http://www.highcharts.com/products/highcharts

14

Appendix C describes the setup of the cloud server consisting of the open source MQTT broker Mosquitto³

, the actual web interface and a Nginx⁴ Hypertext Transfer Protocol (HTTP) server to provide it.

3
https://mosquitto.org/
4
https://nginx.org/

15

# Chapter 5

# Conclusion

This project introduced a Arduino-based smart battery cell research platform. The platform comprises an ESP8266 WiFi SOC on the inexpensive Sparkfun ESP8266 Thing development board. Additional hardware for cell voltage measurement and passive balancing is combined on a simple smart battery cell shield. The CMUs communicate via UDP/IP on a WiFi network created by a Raspberry Pi 3 Model B acting as gateway. The gateway runs a software to relay cell state information and balancing control messages between the cell network and a web service. As a proof-of-concept the communication between the battery pack and a graphical web interface was implemented via the MQTT protocol.
The smart battery cell research platform software currently only supports basic features which are to be researched and extended in the future. Furthermore, the ADC showed significant jitter which has to be reduced by additional hardware and/or filtering software.
Figure 5.1 shows four smart battery cells connected in series powering a light bulb.

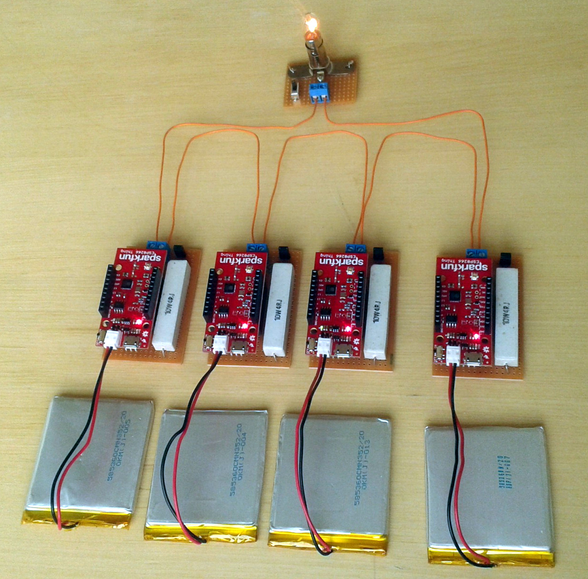
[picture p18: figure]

Figure 5.1: Four smart battery cells connected in series powering a light bulb.

16

# Bibliography

[1] S. Steinhorst, M. Lukasiewycz, S. Narayanaswamy, M. Kauer, and S. Chakraborty, “Smart cells for embedded battery management,” in Proceedings of the 2nd International Conference on Cyber-Physical Systems, Networks, and Applications (CPSNA 2014), pp. 59–64, 9 2014.
[2] S. Steinhorst and M. Lukasiewycz, “Topology identification for smart cells in modular batteries,” in Proceedings of the Conference on Design, Automation and Test in Europe (DATE 2015), pp. 1–4, 3 2015.
[3] N. Martiny, T. Mühlbauer, S. Steinhorst, M. Lukasiewycz, and A. Jossen, “Digital data transmission system with capacitive coupling for in-situ temperature sensing in lithium ion cells,” Journal of Energy Storage, vol. 4, pp. 128–134, 2015.
[4] V. Lorentz, “Electrical energy storage: Distributed battery monitoring.” EES 2012 Electrical Energy Storage Exhibition Munich, Nov. 2012. http://media.nmm.de/91/lorentz_fraunhofer-iisb_14.11.2012_10.30_26767091.pdf. (http://media.nmm.de/91/lorentz_fraunhofer-iisb_14.11.2012_10.30_26767091.pdf)
[5] M. Schneider, S. Ilgin, N. Jegenhorst, R. Kube, S. Püttjer, K. R. Riemschneider, and
J. Vollmer, “Automotive battery monitoring by wireless cell sensors,” in Instrumentation and Measurement Technology Conference (I2MTC), 2012 IEEE International, pp. 816–820, May 2012.
[6] Espressif, “ESP8266EX Datasheet 2016 v4.9.” https://espressif.com/sites/default/files/documentation/0a-esp8266ex_datasheet_en.pdf, (https://espressif.com/sites/default/files/documentation/0a-esp8266ex_datasheet_en.pdf) 2016. Accessed: 2016-08-30.
[7] Texas Instruments, “CC3200 SimpleLinkTM Wi-Fi
R and Internet-of-Things Solution, a Single-Chip Wireless MCU.” http://www.ti.com/lit/gpn/cc3200, Feb. 2015. Accessed: 2016-08-30.
[8] STMicroelectronics, “STM32F407/417.” http://www.st.com/en/microcontrollers/stm32f407-417.html. (http://www.st.com/en/microcontrollers/stm32f407-417.html) Accessed: 2016-08-30.
[9] Jim Lindblom, “SparkFun_ESP8266_Thing.” Schematic, https://cdn.sparkfun.com/datasheets/Wireless/WiFi/SparkFun_ESP8266_Thing.pdf, (https://cdn.sparkfun.com/datasheets/Wireless/WiFi/SparkFun_ESP8266_Thing.pdf) May 2015. Accessed: 2016-10-16.
[10] M. Isaacson, R. Hollandsworth, P. Giampaoli, F. Linkowsky, A. Salim, and V. Teofilo, “Advanced lithium ion battery charger,” in Battery Conference on Applications and Advances, 2000. The Fifteenth Annual, pp. 193–198, IEEE, 2000.

17

# Appendix A

# Zip Archive

Folder | Description
cmu | CMU software
gateway | Gateway software
www | MQTT web interface
eagle | CadSoft EAGLE design files
datasheets | Datasheets of the hardware components

18

# Appendix B

# Setup Gateway

The following setup commands refer to a Raspberry Pi 3 Model B running a fresh install of Raspbian GNU/Linux 8 (jessie).

### Update Raspbian

$ sudo apt-get update
$ sudo apt-get upgrade
$ sudo rpi-update

### Configure WiFi Access Point

Install the hostapd software access point daemon and the dnsmasq network infrastructure packages with the following command.

$ sudo apt-get install hostapd dnsmasq

Stop the DHCP client dhcpcd from configuring wlan0 by adding the following line to the end of the configuration file /etc/dhcpcd.conf.

denyinterfaces wlan0

Edit the wlan0 part of the inteface configuration file /etc/network/interfaces so that it looks like the following in order to configure a static class C network.

allow-hotplug wlan0
iface wlan0 inet static
address 192.168.0.1
netmask 255.255.255.0
network 192.168.0.0
broadcast 192.168.0.255

Open the hostapd configuration with /etc/hostapd/hostapd.conf and change its contents to the following in order to configure the WiFi access point.

# This is the name of the WiFi interface we configured above

interface=wlan0

19

# Use the nl80211 driver with the brcmfmac driver driver=nl80211

# This is the name of the network ssid=SmartCellGateway

# Use the 2.4GHz band

hw_mode=g

# Use channel 6

channel=6

# Enable 802.11n

ieee80211n=1

# Enable WMM

wmm_enabled=1

# Enable 40MHz channels with 20ns guard interval ht_capab=[HT40][SHORT-GI-20][DSSS_CCK-40]

# Accept all MAC addresses

macaddr_acl=0

# Use WPA authentication

auth_algs=1

# Require clients to know the network name ignore_broadcast_ssid=0

# Use WPA2

wpa=2

# Use a pre-shared key

wpa_key_mgmt=WPA-PSK

# The network passphrase

wpa_passphrase=allcellsarebelongtome

# Use AES, instead of TKIP

rsn_pairwise=CCMP

For hostapd to load this configuration on startup open the file /etc/default/hostapd and replace the line

#DAEMON_CONF=""

with the following.

DAEMON_CONF="/etc/hostapd/hostapd.conf"

20

Configure dnsmasq by replacing the contents of /etc/dnsmasq.conf with the following.

interface=wlan0
listen-address=192.168.0.1
bind-interfaces
domain-needed
bogus-priv
dhcp-range=192.168.0.2,192.168.0.254,24h

Reboot the Raspberry Pi.

You should now be able to connect to the WiFi with SSID SmartCellGateway using the pre-shared key ‘allcellsarebelongtome’ as configured above.

### Install Apache Ant and Ivy

Install Apache Ant and Ivy by executing the following commands

$ sudo apt-get install ant ivy
$ sudo ln -s /usr/share/java/ivy.jar /usr/share/ant/lib

### Run Gateway Daemon

Copy the gateway daemon sources from appendix A to the Raspberry Pi and run the daemon with the following command.

$ ant daemon

21

# Appendix C

# Setup Cloud Server

### Configure Firewall

Add the following firewall rules to your system.

Protocol | Port | Description
TCP | 80 | HTTP
TCP | 1883 | MQTT
TCP | 9001 | Websocket MQTT

### Install Docker Engine

Follow the instructions on https://docs.docker.com/engine/installation/linux/ubuntulinux/ to install the latest Docker Engine needed to run docker images.

### Install Docker Compose

Execute the following commands in a terminal to install the Docker Compose version 1.8.1.

$ curl -L https://github.com/docker/compose/releases/download/1.8.1/docker-compose-‘uname -s‘-‘uname -m‘ > /tmp/docker-compose
$ sudo mv /tmp/docker-compose /usr/bin
$ sudo chmod 755 /usr/bin/docker-compose

### Create Docker Compose File

Create a docker compose file named mosquitto+nginx.yml with the following content.

version: ’2’
services:
mqtt:
container_name: "mqtt"
image: toke/mosquitto
ports:
- 1883:1883
- 9001:9001

22

web:
container_name: "web"
image: kyma/docker-nginx
ports:
- 80:80
volumes:
- ~/www:/var/www

It runs two docker containers. The first container, named mqtt, starts the open source MQTT broker Mosquitto listening on port 1883 for MQTT and port 9001 for Websocket MQTT client connections. The second container, named web, starts the open source static HTTP web server Nginx listening on port 80 and providing the contents of the directory ~/www.

### Create Web Content

Create at least a index.html file in ~/www. You can, for example, use the Eclipse Paho JavaScript Client¹
library to interface the MQTT broker on the cloud server. Appendix A contains an index.html which displays the cell voltages in a graph and allows to control the cell balancing via MQTT.

### Start MQTT Broker and HTTP Server

Execute the following command to start the docker containers with Docker Compose:

$ docker-compose -f mosquitto+nginx.yml up -d

1
https://eclipse.org/paho/clients/js/

23

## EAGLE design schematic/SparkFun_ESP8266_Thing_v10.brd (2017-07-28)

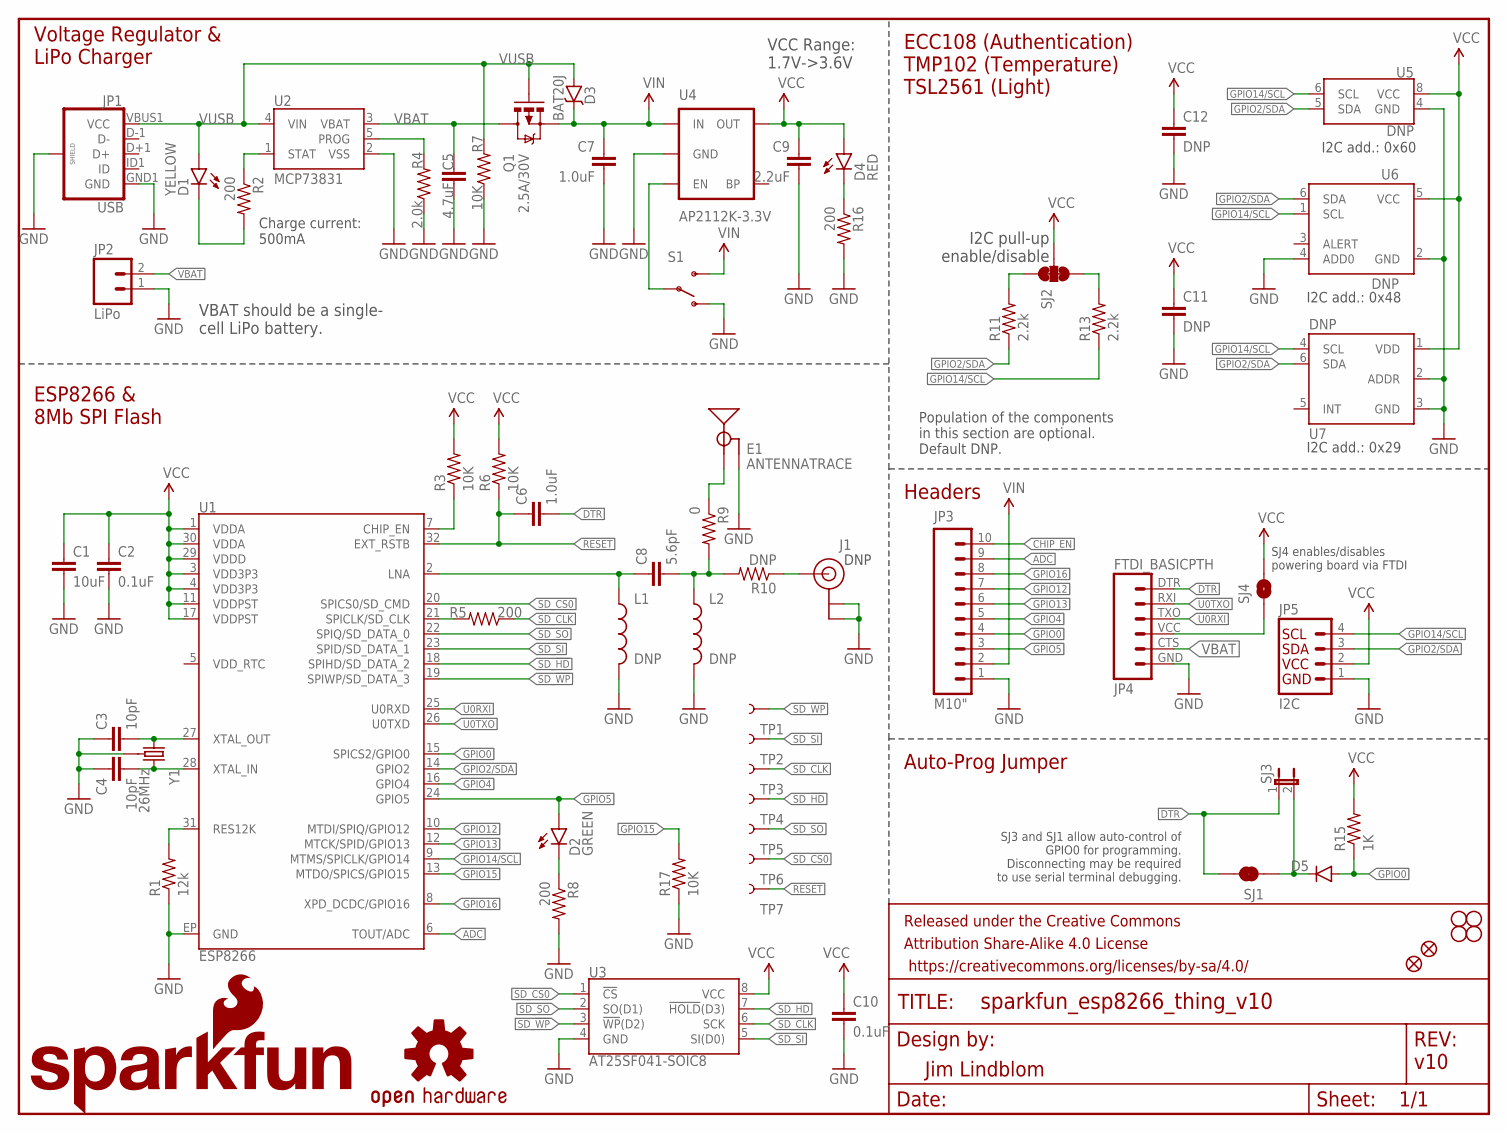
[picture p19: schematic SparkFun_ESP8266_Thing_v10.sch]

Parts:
C1: 10uF; 0603-CAP
C2, C10: 0.1uF; 0603-CAP
C3, C4: 10pF; 0603-CAP
C5: 4.7uF; 0603-CAP
C6: 1.0uF; 0603-CAP
C7: 1.0uF; 0805
C8: 5.6pF; 0603-CAP
C9: 2.2uF; 0603-CAP
C11, C12: DNP; 0603-CAP
D1: YELLOW; LED-0603
D2: GREEN; LED-0603
D3: BAT20J; SOD-323
D4: RED; LED-0603
D5: DIODEBAS16; SOD-323
E1: ANTENNATRACE; TRACE_ANTENNA_2.4GHZ_25.7MM
FID1, FID2: FIDUCIAL1X2; FIDUCIAL-1X2
FRAME1: FRAME-LETTER; CREATIVE_COMMONS
J1: DNP; U.FL
JP1: USB; USB-B-MICRO-SMD_V03
JP2: LiPo; JST-2-PTH
JP3: M10"; 1X10
JP4: FTDI_BASICPTH; FTDI_BASIC
JP5: I2C; 1X04
L1, L2: DNP; 0603
LOGO1: SFE_LOGO_NAME.2_INCH; SFE_LOGO_NAME_.2
LOGO3: SFE_LOGO_FLAME.1_INCH; SFE_LOGO_FLAME_.1
LOGO4: OSHW-LOGOS; OSHW-LOGO-S
Q1: 2.5A/30V; SOT23-3
R1: 12k; 0603-RES
R2, R5, R8, R16: 200; 0603-RES
R3, R6, R7, R17: 10K; 0603-RES
R4: 2.0k; 0603-RES
R9: 0; 0603
R10: DNP; 0603-RES
R11, R13: 2.2k; 0603-RES
R15: 1K; 0603-RES
S1: SWITCH-SPDT-SMD-A; SWITCH-SPST-SMD-A
SJ1: JUMPER-PAD-2-NC_BY_TRACE; PAD-JUMPER-2-NC_BY_TRACE_YES_SILK
SJ2: JUMPER-PAD-3-NC_BY_TRACE; PAD-JUMPER-3-3OF3_NC_BY_TRACE_YES_SILK_FULL_BOX
SJ3: JUMPER-PTH-2-NC; PTH-JUMPER-NC_BOTTOM_NO_SILK
SJ4: JUMPER-PAD-2-NOYES_SILK; PAD-JUMPER-2-NO_YES_SILK
STANDOFF1, STANDOFF2, STANDOFF3, STANDOFF4: STAND-OFF
TP1, TP2, TP3, TP4, TP5, TP6, TP7: TEST-POINT3X5; PAD.03X.05
U1: ESP8266; QFN32
U2: MCP73831; SOT23-5
U3: AT25SF041-SOIC8; SO08
U4: AP2112K-3.3V; SOT23-5
U5: DNP; UDFN8
U6: DNP; SOT563-2
U7: DNP; FN-6
Y1: 26MHz; CRYSTAL-SMD-3.2X2.5

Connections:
ADC: JP3.9, U1.6 (TOUT/ADC)
ANT: J1.P$3 (SIGNAL), R10.1
CHIP_EN: JP3.10, R3.1, U1.7 (CHIP_EN)
DTR: C6.2, JP4.DTR (1), SJ1.2, SJ3.1
FTDI_VCC: JP4.VCC (4), SJ4.1
GND: C1.2, C2.2, C3.1, C4.1, C5.2, C7.2, C9.2, C10.2, C11.2, C12.2, E1.GND, E1.GND2 (GND), J1.P$1 (GND), J1.P$2 (GND), JP1.GND1 (GND), JP1.SHIELD1 (SHIELD), JP1.SHIELD2 (SHIELD), JP1.SHIELD3 (SHIELD), JP2.1, JP3.1, JP4.GND (6), JP5.1, L1.2, L2.2, R1.1, R4.1, R7.1, R8.2, R16.2, R17.1, S1.1 (O), U1.EP (GND), U2.2 (VSS), U3.4 (GND), U4.2 (GND), U5.4 (GND), U6.2 (GND), U6.4 (ADD0), U7.2 (ADDR), U7.3 (GND), Y1.2 (GND), Y1.4 (GND)
GPIO0: D5.A, JP3.4, R15.1, U1.15 (SPICS2/GPIO0)
GPIO2/SDA: JP5.3, R11.1, U1.14 (GPIO2), U5.5 (SDA), U6.6 (SDA), U7.6 (SDA)
GPIO4: JP3.5, U1.16 (GPIO4)
GPIO5: D2.A, JP3.3, U1.24 (GPIO5)
GPIO12: JP3.7, U1.10 (MTDI/SPIQ/GPIO12)
GPIO13: JP3.6, U1.12 (MTCK/SPID/GPIO13)
GPIO14/SCL: JP5.4, R13.1, U1.9 (MTMS/SPICLK/GPIO14), U5.6 (SCL), U6.1 (SCL), U7.4 (SCL)
GPIO15: R17.2, U1.13 (MTDO/SPICS/GPIO15)
GPIO16: JP3.8, U1.8 (XPD_DCDC/GPIO16)
LNA: C8.1, L1.1, U1.2 (LNA)
unnamed: R1.2, U1.31 (RES12K)
unnamed: C4.2, U1.28 (XTAL_IN), Y1.3 (2)
unnamed: C3.2, U1.27 (XTAL_OUT), Y1.1
unnamed: D4.C, R16.1
unnamed: C8.2, L2.1, R9.2, R10.2
unnamed: R5.2, U1.21 (SPICLK/SD_CLK)
unnamed: D5.C, SJ1.1, SJ3.2
unnamed: R11.2, SJ2.1
unnamed: R13.2, SJ2.3
unnamed: S1.2, U4.3 (EN)
unnamed: R4.2, U2.5 (PROG)
unnamed: D2.C, R8.1
unnamed: D1.C, R2.2
unnamed: R2.1, U2.1 (STAT)
RESET: C6.1, R6.1, TP7.P$1, U1.32 (EXT_RSTB)
SD_!HD!: TP4.P$1, U1.18 (SPIHD/SD_DATA_2), U3.7 (!HOLD!(D3))
SD_!WP!: TP1.P$1, U1.19 (SPIWP/SD_DATA_3), U3.3 (!WP!(D2))
SD_CLK: R5.1, TP3.P$1, U3.6 (SCK)
SD_CS0: TP6.P$1, U1.20 (SPICS0/SD_CMD), U3.1 (!CS!)
SD_SI: TP2.P$1, U1.23 (SPID/SD_DATA_1), U3.5 (SI(D0))
SD_SO: TP5.P$1, U1.22 (SPIQ/SD_DATA_0), U3.2 (SO(D1))
TRACE_ANT: E1.ANT (SIGNAL), R9.1
U0RXI: JP4.TXO (3), U1.25 (U0RXD)
U0TXO: JP4.RXI (2), U1.26 (U0TXD)
VBAT: C5.1, JP2.2, JP4.CTS (5), Q1.3 (D), U2.3 (VBAT)
VCC: C1.1, C2.1, C9.1, C10.1, C11.1, C12.1, D4.A, JP5.2, R3.2, R6.2, R15.2, SJ2.2, SJ4.2, U1.1 (VDDA), U1.3 (VDD3P3), U1.4 (VDD3P3), U1.11 (VDDPST), U1.17 (VDDPST), U1.29 (VDDD), U1.30 (VDDA), U3.8 (VCC), U4.5 (OUT), U5.8 (VCC), U6.5 (VCC), U7.1 (VDD)
VIN: C7.1, D3.C, JP3.2, Q1.2 (S), S1.3 (S), U4.1 (IN)
VUSB: D1.A, D3.A, JP1.VBUS1 (VCC), Q1.1 (G), R7.2, U2.4 (VIN)

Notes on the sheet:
Jim Lindblom
ECC108 (Authentication) TMP102 (Temperature) TSL2561 (Light)
Voltage Regulator & LiPo Charger
ESP8266 & 8Mb SPI Flash
Headers
Auto-Prog Jumper
v10
VCC Range: 1.7V->3.6V
VBAT should be a single- cell LiPo battery.
I2C pull-up enable/disable
SJ4 enables/disables powering board via FTDI
SJ3 and SJ1 allow auto-control of GPIO0 for programming. Disconnecting may be required to use serial terminal debugging.
I2C add.: 0x48
I2C add.: 0x60
I2C add.: 0x29
Population of the components in this section are optional. Default DNP.
Charge current: 500mA
DNP

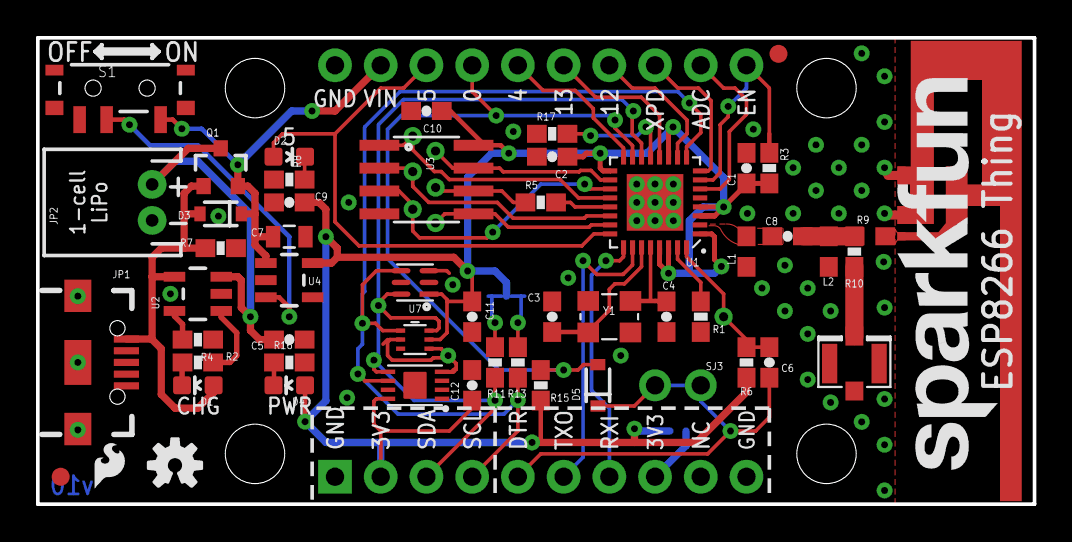
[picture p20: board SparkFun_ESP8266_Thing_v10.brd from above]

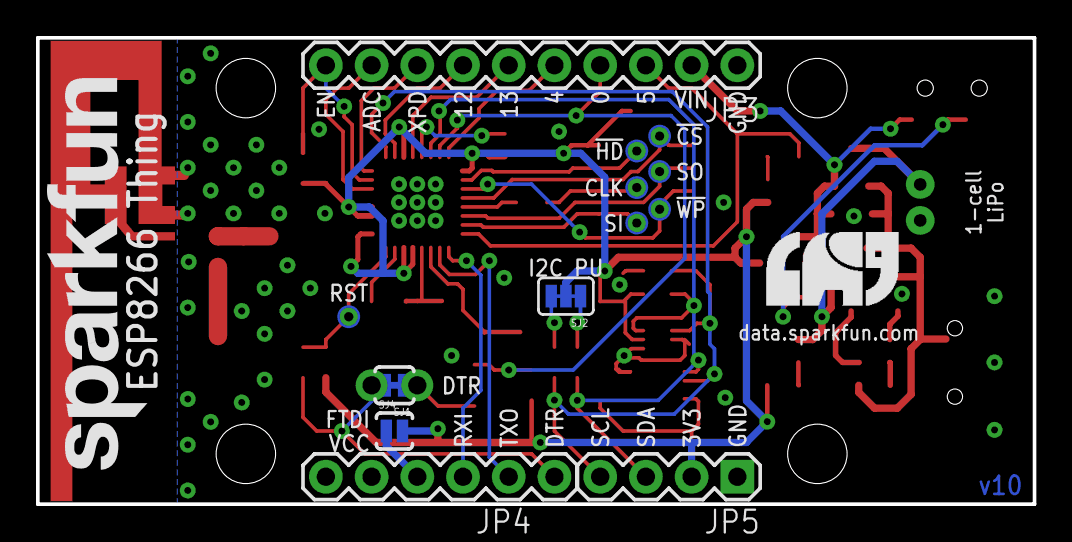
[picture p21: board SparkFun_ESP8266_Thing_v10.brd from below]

Board: 2 copper layers, 55.4 x 25.9 mm, 73 parts (14 on the bottom side), 44 nets.

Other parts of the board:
LOGO5: SFE_LOGO_NAME.2_INCH; SFE_LOGO_NAME_.2

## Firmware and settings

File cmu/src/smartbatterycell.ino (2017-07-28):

/*
	Smart Battery Cell

	Created 2016-08-29
	Christian Siegel, Aarhus University
*/

#include <ESP8266WiFi.h>
#include <WiFiUdp.h>

///////////////////////////////////////////////////////////////////////////////
// Config
///////////////////////////////////////////////////////////////////////////////

const int PIN_ADC_BATTERY = A0;
const int PIN_ADC_GROUND = 4;
const int PIN_MOSFET = 5;

// Needs to be class C network.
//const char* WIFI_SSID = "Internet";
//const char* WIFI_PASSPHRASE = "sX989oDXcKCyTXaO";

const char* WIFI_SSID = "SmartCellGateway";
const char* WIFI_PASSPHRASE = "allyourcellsarebelongtome";

const uint16_t PORT = 4444;

// Time in ms after which cached cell states are dropped.
const uint16_t CELL_CACHE_MEMORY = 2000; // 2 seconds

// Interval after which the cell state is broadcasted
const uint16_t STATE_BROADCAST_INTERVAL = 500;

///////////////////////////////////////////////////////////////////////////////
// Enumeration Types
///////////////////////////////////////////////////////////////////////////////

// Message types used as message headers in order to distinguish between them.
typedef enum {
    // Message containing the state of a single cell.
    MESSAGE_STATE_UPDATE = 0,
    // Message to set the balancing mode of cells (see also balancingType_t).
    MESSAGE_BALANCING_CONTROL = 1,
} messageType_t;

// Balancing mode a cell can perform.
typedef enum {
    // Manual passive balancing (controlled by external messages).
    BALANCING_PASSIVE_MANUAL = 0,
    // Continuous auto passive balancing
    BALANCING_PASSIVE_AUTO = 1,
} balancingMode_t;

///////////////////////////////////////////////////////////////////////////////
// Structure types
///////////////////////////////////////////////////////////////////////////////

// Full state information of a cell.
typedef struct {
    // Voltage in mV.
    uint16_t voltage;
    // State of the passive balancing.
    bool isBalancing;
    // Active balancing mode.
    balancingMode_t balancingMode;
} cellState_t;

// Aggregated state information of the battery pack.
typedef struct {
    // Minimum cell voltage in the pack [mV].
    uint16_t voltageMin;
    // Maximum cell voltage in the pack [mV].
    uint16_t voltageMax;
    // Mean cell voltage in the pack [mV].
    uint16_t voltageMean;
    // Number of cells in the pack.
    uint8_t numberOfCells;
} aggregatedPackState_t;

// Reduced cell state information used to cache all cells and
// aggregate their values.
typedef struct {
    // Voltage in mV.
    uint16_t voltage;
    // Timestamp of last update in ms (see millis()).
    uint32_t lastUpdated;
} cellCacheEntity_t;

///////////////////////////////////////////////////////////////////////////////
// Constants 
///////////////////////////////////////////////////////////////////////////////

// Size of cell cache for aggregation.
// (Since there are 254 possible hosts in class C network subnet the last o
// octed -1 of the cell's IP can be used as cache index (1-1=0 to 254-1=253).)
const uint8_t CELL_CACHE_SIZE = 254;

// Size of message buffer in bytes.
const uint8_t MESSAGE_BUFFER_SIZE = 10;

///////////////////////////////////////////////////////////////////////////////
// Global variables
///////////////////////////////////////////////////////////////////////////////

WiFiUDP udp;

// Cached cell information.
// The last octet -1 of the cell's IP is used as index (1-1=0 to 254-1=253).
cellCacheEntity_t cellCache[CELL_CACHE_SIZE];

// Cached aggregated pack state.
aggregatedPackState_t packCache = {
    0, // voltageMin
    0, // voltageMax
    0, // voltageMean
    0, // numberOfCells
};

// State of the cell.
cellState_t state = {
    0,                        // voltage
    false,                    // isBalancing
    BALANCING_PASSIVE_AUTO,   // balancingMode
};

// Timestamp of last cell state message broadcast
uint32_t lastStateBroadcast = 0;

///////////////////////////////////////////////////////////////////////////////
// Functions
///////////////////////////////////////////////////////////////////////////////

// Inits GPIO of ESP8266.
void initGPIO() {
    // Init PIN_ADC_GROUND as output and set it to low in
    // order to use it as ground for ADC voltage divider.
    pinMode(PIN_ADC_GROUND, OUTPUT);
    digitalWrite(PIN_ADC_GROUND, LOW);

    // Init PIN_MOSFET as output and initially set it to low.
    pinMode(PIN_MOSFET, OUTPUT);
    digitalWrite(PIN_MOSFET, LOW);
}

// Connects to WiFi using the configured WIFI_SSID and WIFI_PASSPHRASE.
void initNetwork() {
    Serial.print("Connecting to WiFi \"");
    Serial.print(WIFI_SSID);
    Serial.print("\"");

    WiFi.begin(WIFI_SSID, WIFI_PASSPHRASE);
    while (WiFi.status() != WL_CONNECTED) {
        Serial.print(".");
        delay(500);
    }

    Serial.println();
    Serial.print("IP address: ");
    Serial.println(WiFi.localIP());
    Serial.println();
}

// Binds UDP socket to PORT
void initSocket() {
    Serial.println("Creating UDP socket...");

    udp.begin(PORT);

    Serial.print("Local port: ");
    Serial.println(udp.localPort());
    Serial.println();
}

// Clears cell cache.
void clearCellCache() {
    for(uint8_t i = 0; i < CELL_CACHE_SIZE; ++i) {
        cellCache[i].lastUpdated = 0;
    }
}

void setup() {
    Serial.begin(115200);
    Serial.println();

    initGPIO();
    initNetwork();
    initSocket();

    clearCellCache();
}

// Updates cached cell state.
void updateCachedCellState(uint8_t idx, const cellState_t &cell) {
    cellCache[idx].voltage = cell.voltage;
    cellCache[idx].lastUpdated = millis();
}

// Updates cached cell state.
void updateCachedCellState(const IPAddress &cellIP, const cellState_t &cell) {
    updateCachedCellState(cellIP[3] - 1, cell);
}

// Gets cached cell state.
// Returns TRUE if cached cell state was updated within CELL_CACHE_MEMORY,
// otherwise FALSE is returned and cell is undefined.
bool getCachedCellState(uint8_t idx, cellCacheEntity_t **cell) {
    if(cellCache[idx].lastUpdated == 0) {
        return false;
    } else if(cellCache[idx].lastUpdated + CELL_CACHE_MEMORY < millis()) {
        cellCache[idx].lastUpdated = 0;
        return false;
    } else {
        *cell = &cellCache[idx];
        return true;
    }
}

// Updates cached pack state.
void updateCachedPackState(const aggregatedPackState_t &pack) {
    memcpy(&packCache, &pack, sizeof(aggregatedPackState_t));
}

// Aggregates the currently cached cell states to a pack state.
aggregatedPackState_t aggregatePackState() {
    aggregatedPackState_t pack { 0, 0, 0, 0 };
    cellCacheEntity_t *cell;
    uint32_t sum = 0;
    for(uint8_t i = 0; i < CELL_CACHE_SIZE; ++i) {
        if(getCachedCellState(i, &cell)) {
            if(pack.voltageMin == 0 || cell->voltage < pack.voltageMin) {
                pack.voltageMin = cell->voltage;
            }
            if(cell->voltage > pack.voltageMax) {
                pack.voltageMax = cell->voltage;
            }
            sum += cell->voltage;
            pack.numberOfCells++;
        }
    }
    if(pack.numberOfCells != 0) {
        pack.voltageMean = sum / pack.numberOfCells;
    }
    return pack;
}

// Measures cell voltage in mV.
uint16_t measureCellVoltage() {
    uint32_t val = analogRead(PIN_ADC_BATTERY);
    return (val * 7625) / 1408;
}

// Controls balancing circuit according to cell's balancing mode.
// If suppress is TRUE the balancing will be turned off. This can be used to
// suppress the balancing before a measurement.
void doBalancing(boolean suppress) {
    if(state.balancingMode == BALANCING_PASSIVE_AUTO) {
        state.isBalancing = (state.voltage > packCache.voltageMin);
    }
    digitalWrite(PIN_MOSFET, (state.isBalancing && !suppress) ? HIGH : LOW);
}

// Sends len bytes of buffer to ip:port.
void send(const uint8_t* buffer, size_t len, IPAddress ip, uint16_t port) {
    udp.beginPacket(ip, port);
    udp.write(buffer, len);
    udp.endPacket();
}

// Writes cell state message (MESSAGE_STATE) to the given buffer.
// Returns len of message in buffer. If the buffer is to small -1 is returned.
ssize_t writeStateMessage(uint8_t *buffer, size_t len, const cellState_t &cell) {
    if(len < 5) return -1;
    buffer[0] = MESSAGE_STATE_UPDATE;
    buffer[1] = state.voltage >> 8 & 0xff;
    buffer[2] = state.voltage & 0xff;
    buffer[3] = state.isBalancing ? 1 : 0;
    buffer[4] = state.balancingMode;
    return 5;
}

// Handles state update message.
// Updates cached cell state of the sender cell.
void handleStateUpdateMessage(const uint8_t* buffer, size_t len, IPAddress remoteIP, uint16_t remotePort) {
    if(len < 5) return;
    cellState_t cell;
    cell.voltage = (buffer[1] << 8) | (buffer[2] & 0xff);
    cell.isBalancing = buffer[3] == 1;
    cell.balancingMode = (balancingMode_t)buffer[4];

    Serial.print("STATE UPDATE MSG (");
    Serial.print(remoteIP.toString());
    Serial.print("): ");
    Serial.print(cell.voltage);
    Serial.print(" ");
    Serial.print(cell.isBalancing);
    Serial.print(" ");
    Serial.println(cell.balancingMode);

    updateCachedCellState(remoteIP, cell);
}

// Handles balancing control message.
// Updates local cell state with new balancing settings.
void handleBalancingControlMessage(const uint8_t* buffer, size_t len, IPAddress remoteIP, uint16_t remotePort) {
    if(len < 3) return;
    state.balancingMode = (balancingMode_t)buffer[1];

    if(state.balancingMode == BALANCING_PASSIVE_MANUAL) {
        state.isBalancing = buffer[2] == 1;
    }

    Serial.print("BALANCING CONTROL MSG (");
    Serial.print(remoteIP.toString());
    Serial.print("): ");
    Serial.print(state.balancingMode);
    if(state.balancingMode == BALANCING_PASSIVE_MANUAL) {
        Serial.print(" ");
        Serial.print(state.isBalancing);
    }
    Serial.println();
}

void handleMessage(const uint8_t* buffer, size_t len, IPAddress remoteIP, uint16_t remotePort) {
    if(len < 1) return;
    messageType_t type = (messageType_t)buffer[0];
    switch(type) {
        case MESSAGE_STATE_UPDATE: handleStateUpdateMessage(buffer, len, remoteIP, remotePort); break;
        case MESSAGE_BALANCING_CONTROL: handleBalancingControlMessage(buffer, len, remoteIP, remotePort); break;
    }
}

void loop() {
    static uint8_t messageBuffer[MESSAGE_BUFFER_SIZE];
    size_t len;
    IPAddress ip;

    uint32_t now = millis();

    // read and handle messages
    while(udp.parsePacket()) {
        int len = udp.read(messageBuffer, MESSAGE_BUFFER_SIZE);
        handleMessage(messageBuffer, len, udp.remoteIP(), udp.remotePort());
    }

    // control balancing (suppress balancing if we will mesaure within the next 50 ms)
    boolean suppress = lastStateBroadcast + STATE_BROADCAST_INTERVAL <= now + 50;
    doBalancing(suppress);

    if(lastStateBroadcast + STATE_BROADCAST_INTERVAL <= now) {
        // measure cell state
        state.voltage = measureCellVoltage();

        // update own entry in cell cache
        updateCachedCellState(WiFi.localIP(), state);

        // calculate pack state from cell cache and update pack cache
        updateCachedPackState(aggregatePackState());

        // broadcast cell state
        len = writeStateMessage(messageBuffer, MESSAGE_BUFFER_SIZE, state);
        ip.fromString("255.255.255.255");
        send(messageBuffer, len, ip, PORT);

        lastStateBroadcast = now;
    }

    delay(10);
}

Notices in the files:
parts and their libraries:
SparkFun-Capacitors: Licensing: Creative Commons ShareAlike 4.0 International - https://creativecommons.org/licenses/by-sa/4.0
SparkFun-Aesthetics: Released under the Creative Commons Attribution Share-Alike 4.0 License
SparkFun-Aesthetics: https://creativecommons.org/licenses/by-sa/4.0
